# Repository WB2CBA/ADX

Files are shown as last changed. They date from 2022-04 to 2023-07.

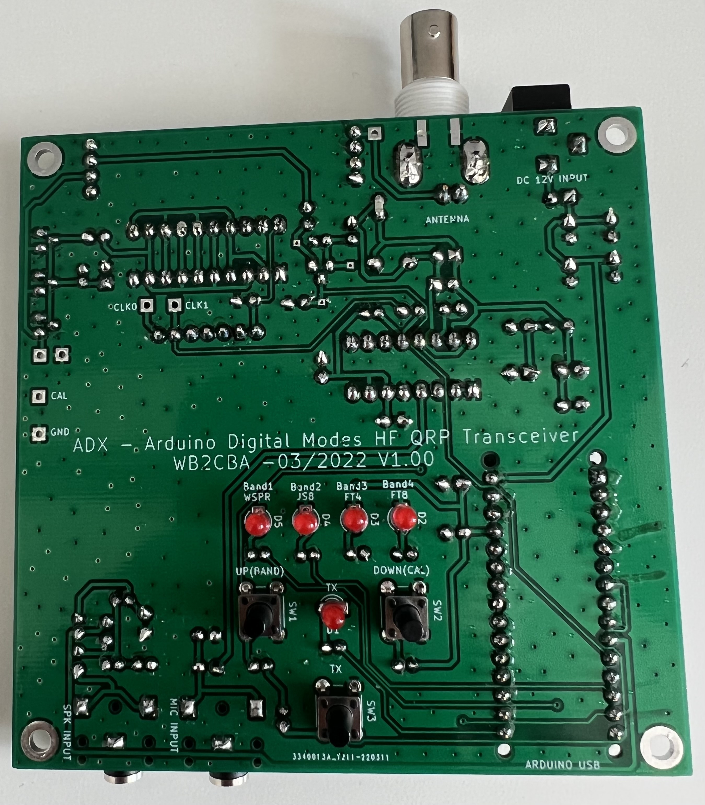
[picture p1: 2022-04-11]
ADX solder side photo.jpg

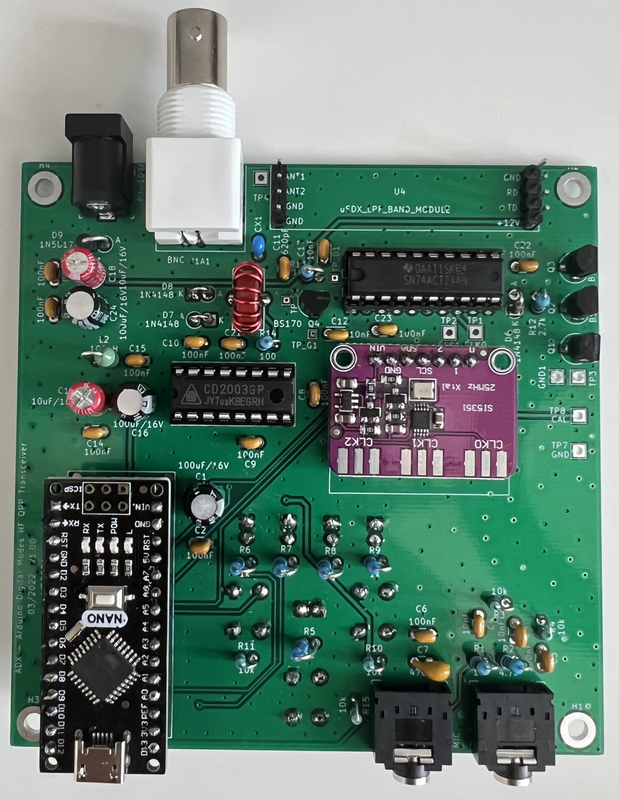
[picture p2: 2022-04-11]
ADX Component side photo.jpg

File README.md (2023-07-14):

ADX - Arduino Digital Modes Transceiver UPDATE (14 July 2023):

- Cowtown Amateur Radio Club ADX Buildathon Construction Manual added.

- I can't thank enough to Richard Hinsley, W5ARH/VK2ARH for putting together this detailed and extremely well put together build manual. 

- ADX Build Manual V1.5 Released.(10 June 2023)

- Calibration Procedure Changed to protect EEPROM from R/W wear out during calibration. (20 December 2022) 

- Caution Note on SI5351 Library.

- ZENER DIODE PA MOSFET PROTECTION to protect PA Mosfets from excessive SWR conditions.(20 December 2022)

- ADX_CAT_V1.6 - Band display bug corrections. Release Date: 14 July 2023  I would like to thank Peter Petrov, LA7WRA and Mark Culross, KD5RXT for spotting this rather embarrasing bug on my part.

-   Firmware release with CAT Control serial baud rate changed to 9600 bps to address problems on TS2000  CAT control on WSJT/X (Hamlib) with 115200 bps. Also excellent code structuring and cleanup  thanks to Joerg Frede,DK3JF. 

- I also added .hex files into ADX Firmware folder. These .hex files can be uploaded to atmega328p microcontroller via ISP port using a programmer like usbasp. 

- These .hex can be used to upload ADX firmware without using Arduino ide and compiling.

- SI5351 Module pull up resistor fix update added to Build Manual V1.4 (08 April 2023)

IMPORTANT NOTE ON NT7S SI5351 LIBRARY VERSIONS   

Please install SI5351 Library that is in ADX Github under ADX Firmware! 
Or use Etherkit SI5351 Library Version 2.1.3. 
ADX firmware is compatible with only Etherkit SI5351 Library version 2.1.3.
____________________________________________________________________________

ADX is an Arduino based Digital Modes Transceiver.

- ADX - is abbreviation for Arduino Digital Xceiver.

- ADX is a mono band (actually quad band) digital modes optimized HF transceiver that can cover four pre-programmed bands one band at a time by swapping Band LPF Modules. 
It can work on 80m, 40m, 30m,20m, 17m, 15m and 10m bands and can operate on four of the most popular digital modes, FT8, FT4, JS8call and WSPR.

- ADX now supports CAT via emulating KENWOOD TS2000 HF Transceiver with 9600 bps,8,1 Serial comm. CAT controls Band and Mode changes.

My goal with this project is to design a simple HF Transceiver optimized for operating on Digital modes:
-	Simple to procure – meaning not effected by chip shortage
-	Simple to build – 2 modules, 2 IC’s and 4 Mosfets!
-	Simple to setup and tune – One simple calibration procedure is all needed.
-	Simple to operate – Plug in ADX MIC to soundcard MIC input and ADX SPK to PC soundcard speaker input and we are good to go with any digital modes Software.
-	Dirt Cheap – Costs less than 25$ to get all parts and PCB if we exclude ridiculous shipping costs!

- Plug in a USB cable between ADX Arduino and your PC, Select Kenwood TS2000 with 9600bps,8,1 setup as your CAT rig and you will have CAT control on ADX!

- For ease of following which parts to solder while building Main board of ADX, Interactive BOM File - ibom_ADX.html file is a great help. Just run that file on Microsoft edge and follow each highlighted component and solder one by one. This interactive BOM was prepared by Gilles DELPECH - F1BFU. Thank you Gilles!

If you like my designs and would like to support my work:
https://www.buymeacoffee.com/wb2cba

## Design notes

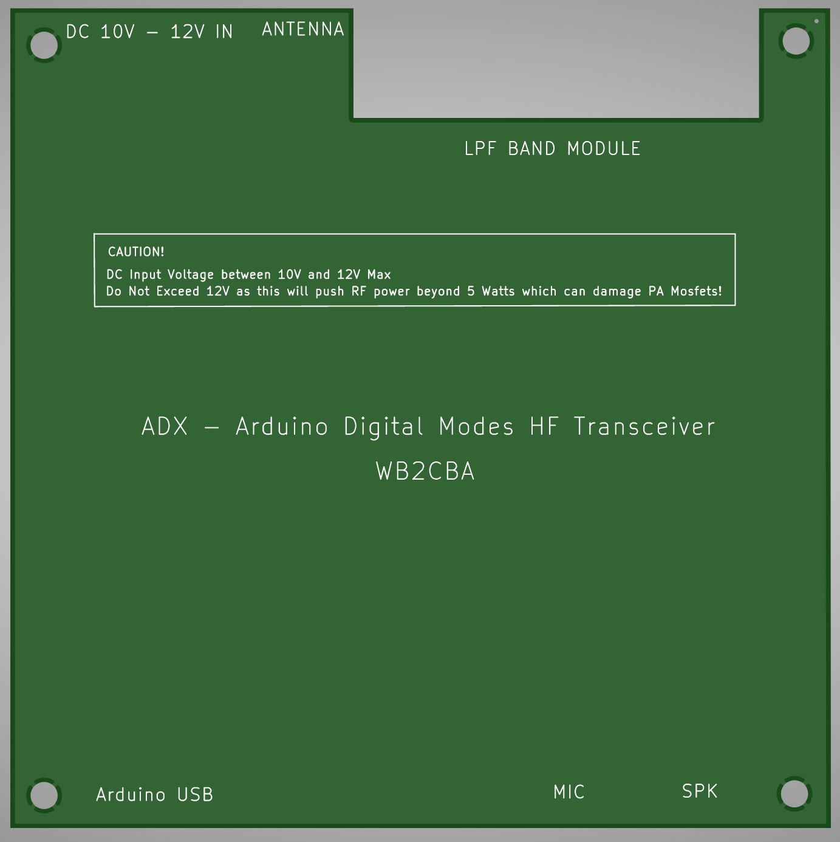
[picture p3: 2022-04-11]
ADX Schematics and Layout/ADX BACK PANEL LAYOUT.jpg

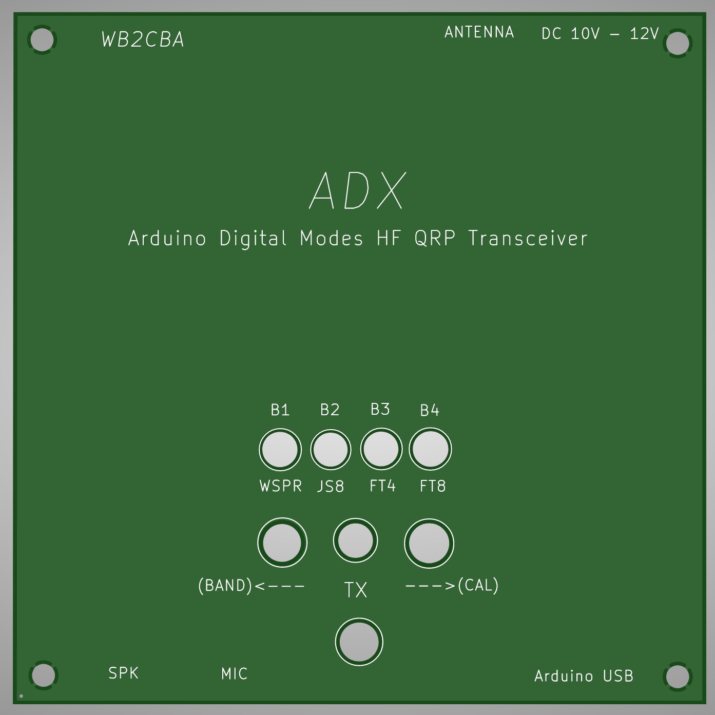
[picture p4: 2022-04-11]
ADX Schematics and Layout/ADX FRONT PANEL LAYOUT.jpg

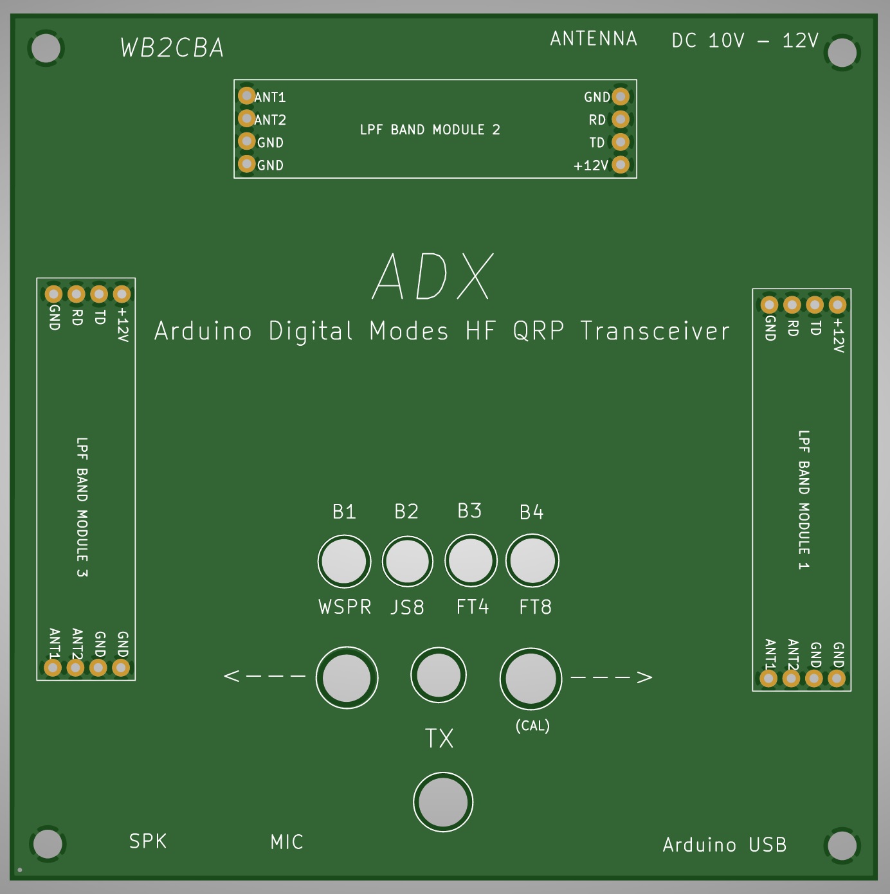
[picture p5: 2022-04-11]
ADX Schematics and Layout/ADX FRONT PANEL with LPF Carrier layout.jpg

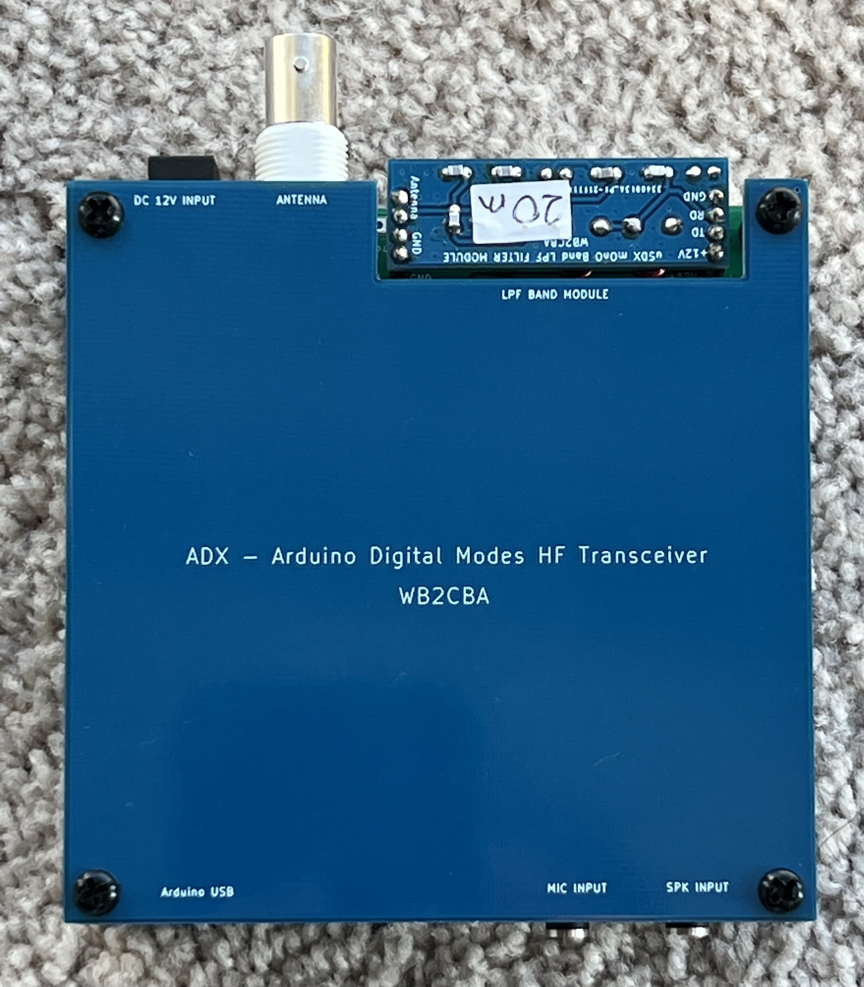
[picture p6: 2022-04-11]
ADX Bottom view.jpg

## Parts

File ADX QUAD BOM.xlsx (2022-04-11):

Part | Designator | Footprint
100uF/16V | C1,C16,C24 | Capacitor_THT:CP_Radial_D5.0mm_P2.50mm
620pF | C11 | Capacitor_THT:C_Disc_D3.0mm_W1.6mm_P2.50mm
10nF | C12,C17 | Capacitor_THT:C_Disc_D3.0mm_W2.0mm_P2.50mm
10uF/16V | C13,C18 | Capacitor_THT:CP_Radial_D5.0mm_P2.50mm
100nF | C2,C3,C6,C8,C9,C10,C14,C15,C19,C20,C21,C22,C23 | Capacitor_THT:C_Disc_D3.0mm_W1.6mm_P2.50mm
10nF | C4,C5 | Capacitor_THT:C_Disc_D3.0mm_W1.6mm_P2.50mm
470nF | C7 | Capacitor_THT:C_Disc_D3.0mm_W1.6mm_P2.50mm
SPK | CON1 | digikey-footprints:Headphone_Jack_3.5mm_SJ1-3523N
MIC | CON2 | digikey-footprints:Headphone_Jack_3.5mm_SJ1-3523N
TX | D1 | LED_THT:LED_D3.0mm
FT8 | D2 | LED_THT:LED_D3.0mm
FT4 | D3 | LED_THT:LED_D3.0mm
JS8 | D4 | LED_THT:LED_D3.0mm
WSPR | D5 | LED_THT:LED_D3.0mm
1N4148 | D6 | Diode_THT:D_A-405_P2.54mm_Vertical_AnodeUp
1N4148 | D7,D8 | Diode_THT:D_A-405_P2.54mm_Vertical_KathodeUp
1N5817 | D9 | Diode_THT:D_A-405_P2.54mm_Vertical_KathodeUp
SMA | J1 | SMA_EDGE:SMA_Samtec_SMA-J-P-X-ST-EM1_EdgeMount
BNC | J1A1 | Connector_Coaxial:BNC_Amphenol_B6252HB-NPP3G-50_Horizontal
PJ-102A | J2 | digikey-footprints:Barrel_Jack_5.5mmODx2.1mmID_PJ-102A
1uH | L1 | Inductor_THT:L_Toroid_Vertical_L10.0mm_W5.0mm_P5.08mm
100uH | L2 | Resistor_THT:R_Axial_DIN0204_L3.6mm_D1.6mm_P2.54mm_Vertical
BS170 | Q1,Q2,Q3 | Package_TO_SOT_THT:TO-92_HandSolder
BS170 | Q4 | Package_TO_SOT_THT:TO-92L_HandSolder
1M | R1 | Resistor_THT:R_Axial_DIN0204_L3.6mm_D1.6mm_P1.90mm_Vertical
2.7k | R12 | Resistor_THT:R_Axial_DIN0204_L3.6mm_D1.6mm_P1.90mm_Vertical
100 | R14 | Resistor_THT:R_Axial_DIN0204_L3.6mm_D1.6mm_P1.90mm_Vertical
4.7k | R2 | Resistor_THT:R_Axial_DIN0204_L3.6mm_D1.6mm_P1.90mm_Vertical
10k | R3,R4,R10,R11,R15 | Resistor_THT:R_Axial_DIN0204_L3.6mm_D1.6mm_P1.90mm_Vertical
1k | R5,R6,R7,R8,R9,R13 | Resistor_THT:R_Axial_DIN0204_L3.6mm_D1.6mm_P1.90mm_Vertical
UP(BAND) | SW1 | Button_Switch_THT:SW_PUSH_6mm
DOWN(CAL) | SW2 | Button_Switch_THT:SW_PUSH_6mm
TX | SW3 | Button_Switch_THT:SW_PUSH_6mm
CD2003GB_GP | U1 | Package_DIP:DIP-16_W7.62mm_Socket_LongPads
SI5351_Module | U2 | VFO_footprint:SI5351 Module_Vertical
74ACT244 | U3 | Package_DIP:DIP-20_W7.62mm_LongPads
uSDX_LPF_BAND_MODULE | U4 | uSDX_LPF_BAND_MODULE:uSDX_mOnO LPF_Band_Module
Arduino_Nano_Socket | XA1 | Arduino:Arduino_Nano

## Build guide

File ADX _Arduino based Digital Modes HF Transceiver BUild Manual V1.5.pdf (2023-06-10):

## ADX – An Arduino based HF Digital Modes Transceiver

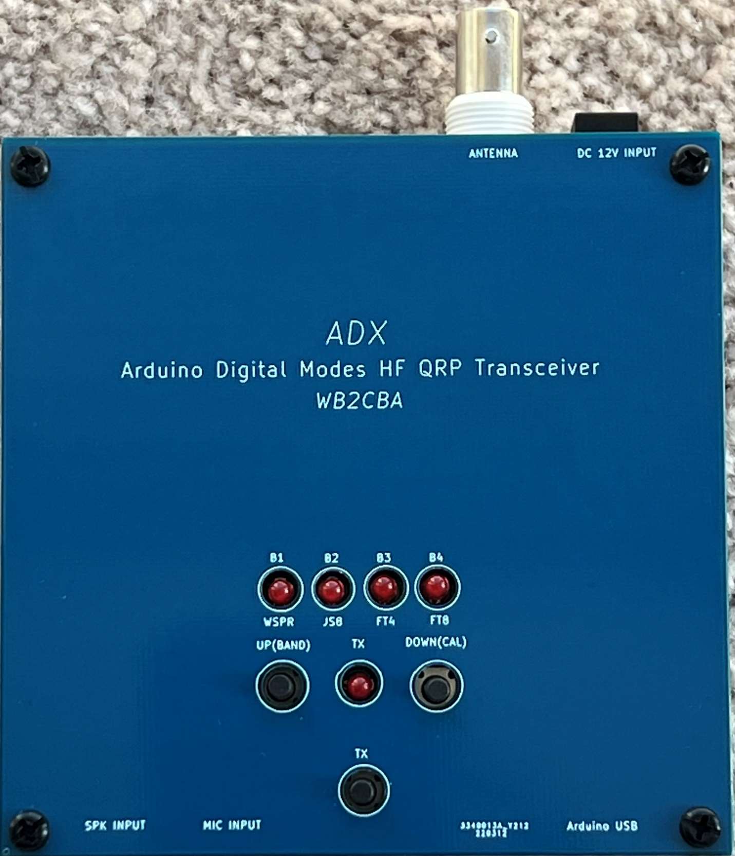
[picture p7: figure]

## Build Manual V1.5

## UPDATE:

- Calibration Procedure Change.
- Caution Note on SI5351 Library.
- ZENER DIODE PA MOSFET PROTECTION.
- CAT Control Functionality added. Changing CAT baud rate to 9600 bps as hamlib has problems with 115200 bps for TS2000.
- FSK TX code improved to perform under 500 Hz audio TX.
- ADX_CAT_VX.X Firmware
- SI5351 Module Pull UP Resistor FIX
ADX is an Arduino based Digital Modes Transceiver. ADX is abbreviation for Arduino Digital Xceiver. So where does thing come from?

When QRP labs released QDX Transceiver for Digital Modes I watched with fascination Hans Summers’s youtube video explaining details of QDX. For me QDX is the perfect optimized Transceiver for digital modes. Inspired by QDX I decided to put together my own!
Of course I wasn’t Hans Summers and QRP Labs so no way I had all that programming and RF skills to create something as sophisticated as QDX so I cheated and settled for something super stripped and simple! I christened it as ADX. It has an Arduino which justifies “A” and it is for digital modes so a “D” and it is a transceiver so it is a “X”! ADX fit that purpose for naming

convention quite nicely!
ADX is a mono band (actually quad band) digital modes optimized HF transceiver that can cover four pre-programmed bands one band at a time! More on that later. It can work on 80m,40m,30m,20m, 17m, 15m and 10m bands and also covers four of the most popular digital modes, FT8, FT4, JS8call and WSPR. I thought about using SA612 though this CD2003GP IC gave much better sensitivity results as it has a RF preamplifier section and it is dirt cheap and readily available from every online Chinese marketing site!
My goal with this project is to design a simple HF QRP Transceiver optimized for Digital modes:
- Simple to procure – meaning not effected by chip shortage
- Simple to build – 2 modules, 2 IC’s and 4 Mosfets!
- Simple to setup and tune – One simple calibration procedure is all needed.

- Simple to operate – Plug in ADX MIC to soundcard MIC input and ADX SPK to PC soundcard speaker input and we are good to go with any digital modes Software.
- Dirt Cheap – Costs less than 25$ to get all parts and PCB if we exclude ridiculous shipping costs! ADX Building Blocks:

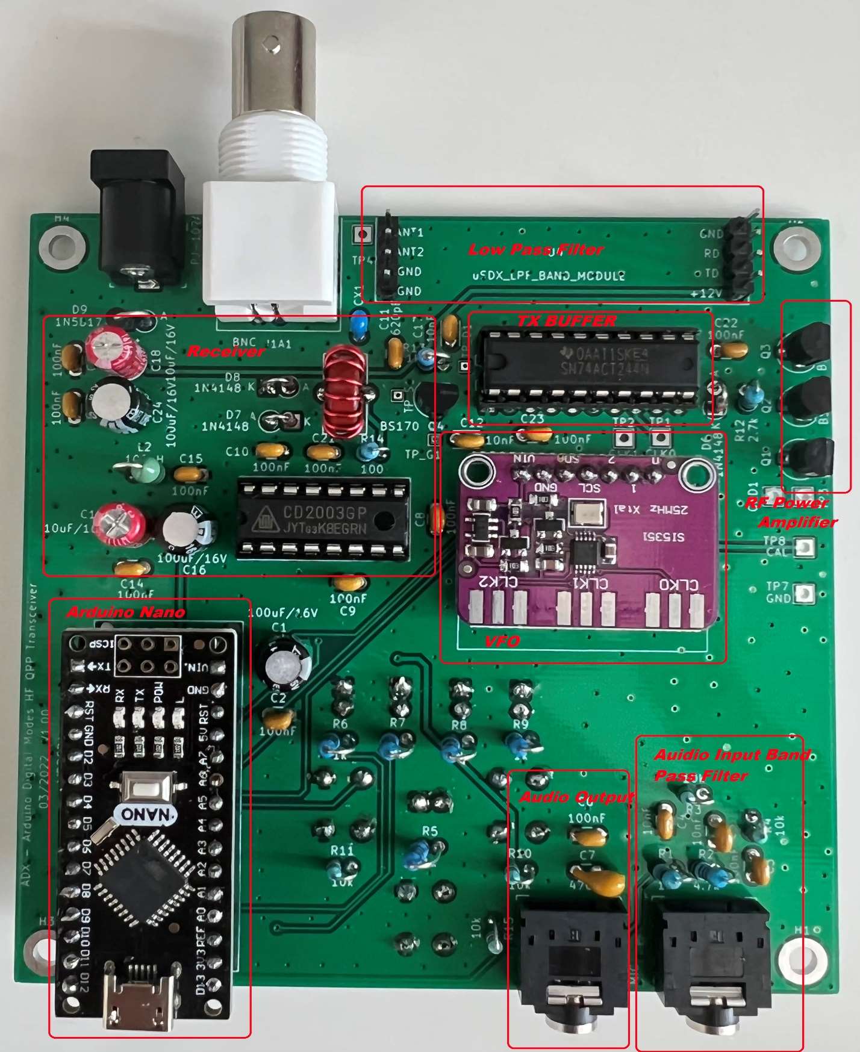
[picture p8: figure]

Building blocks of ADX Transceiver:
- Brain of ADX is an Arduino Nano which takes care of signal generation from audio tones of digital modes, user interface and calibration of SI5351 Module. ADX uses direct FSK Signal generating method similar to QDX or QRPGUYS Digital Transceiver III.
- Audio interface consists of a Speaker input from PC sound card which is actually an input to Arduino nano analog comparator for tone frequency detection and sampling. Before inputting signal to analog comparator of Arduino it passes through a band pass filter which has an audio band pass frequency range of 500 Hz to 3500 Hz.

This input acts like a VOX so no need for any PTT or serial PTT CAT input. When ADX hears a tone from for example WSJT/X audio output it starts transmitting. And when the tone of digital mode stops it stops TX. It’s that simple. The AFP-FSK (Audio frequency processed Frequency shift keying) technique used in ADX is developed by Burkhard Kainka(DK7JD) - http://elektronik-labor.de/HF/SDRtxFSK2.html

So how does this actually work?
Any digital tonal mode consists of varying audio tones that change frequency in relation to the data they correlate to. This audio tone generated for example for FT8 with WSJT/X software is passed through an audio band pass filter and then it is compared with Arduino Nano’s Atmega328P processor A/D comparator for start and stop zero cross detection to determine period of that tone. From that period, frequency of that particular tone that is determined and added to base transmit frequency, for example 14074000 Hz for 20m FT8. If the tone let’s say is 1000 Hz then the carrier TX is now 14074000 Hz + 1000 Hz = 14075000 Hz.
As it is summed it will be in USB frequency range of any SSB receiver though the signal is not pure SSB signal still any SSB TRX set to USB can’t tell the difference! This tone frequency detection and adding to base frequency is continuously repeated 400 times per second and refreshed until the FT8 tone transmission generation is over. In that case TX stops.
What fascinates me about this FSK signal generation technique is to generate a signal that is received in USB without any SSB mixing or filtering which eliminates problems of IMD or phase differences etc that comes with SSB signal generation technique which allows such a simple Transceiver to be conceived with minimal parts.
- VFO: VFO is a classic cheap SI5351 Module from Aliexpress or any other site similar to that. VFO generates CLK0 TX signal, CLK1 RX signal and CLK2 calibration signal. No need to modify SI5351 Module as we did in uSDX rig builds. SI5351 module works in a cozy 400khz I2C speed.
- TX BUFFER: TX buffer is an inverting 74ACT244 octal buffer connected in parallel to drive Class E RF power amplifier consisting of 3 x BS170 mosfets. RF power output -varies from band to band - around 5 watts.
- Low Pass Filter Module is a serial resonance class E LPF filter similar to that one used in uSDX designs.
- RECEIVER is CD2003GP – A Chinese clone of Toshiba’s TA2003GP AM/FM radio IC. Only AM section is used as a direct conversion receiver.
- And some caps for RF and VCC filtering etc.
- 5 LEDs and three tactile pushbutton switches for user visual interface and controls. No fancy displays or rotary encoders!
- Now we have CAT support!

Here is ADX Schematics:

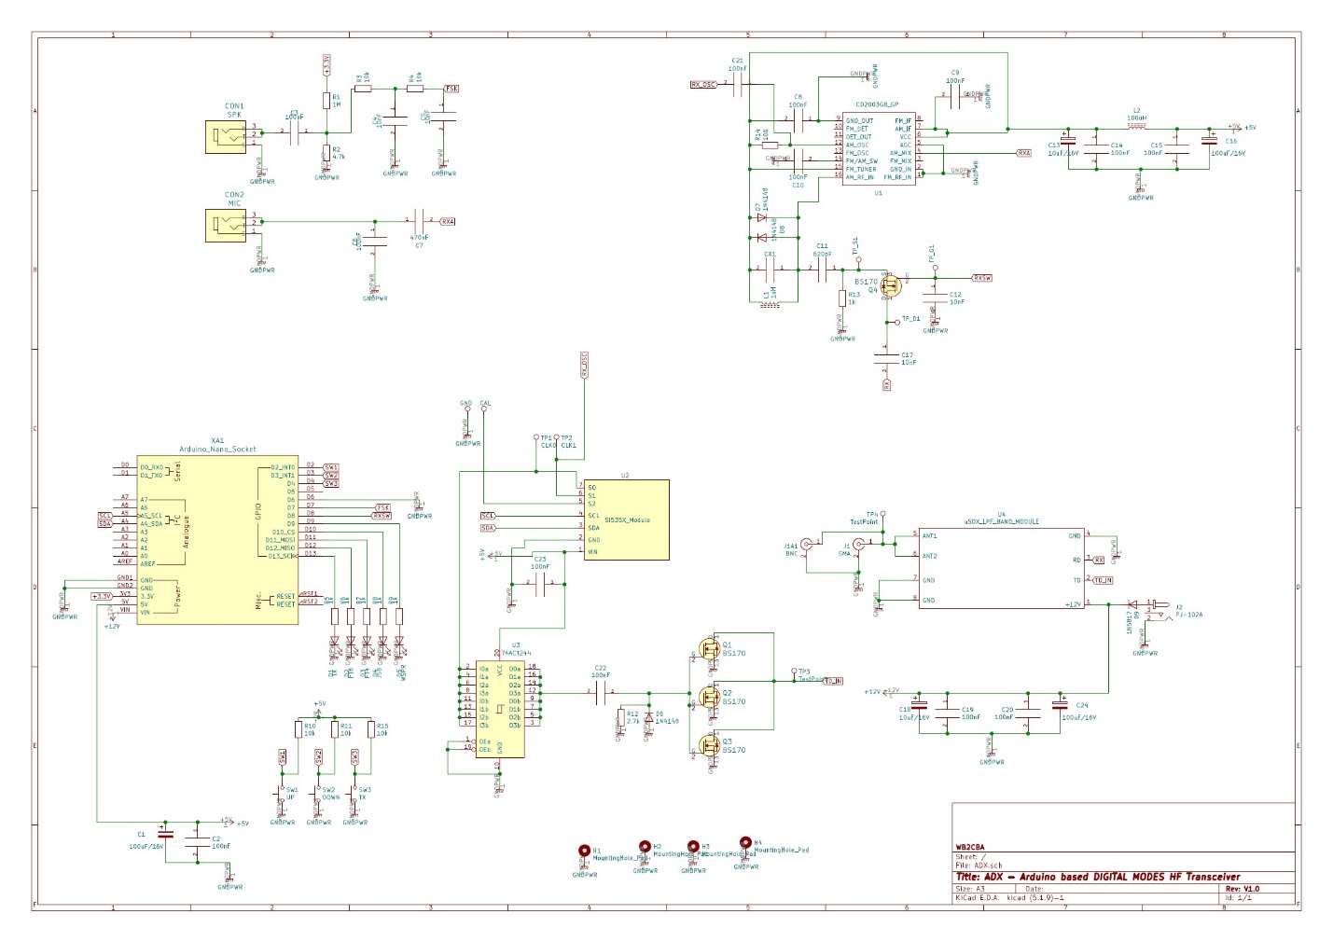
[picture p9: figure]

Here is ADX PCB layouts:

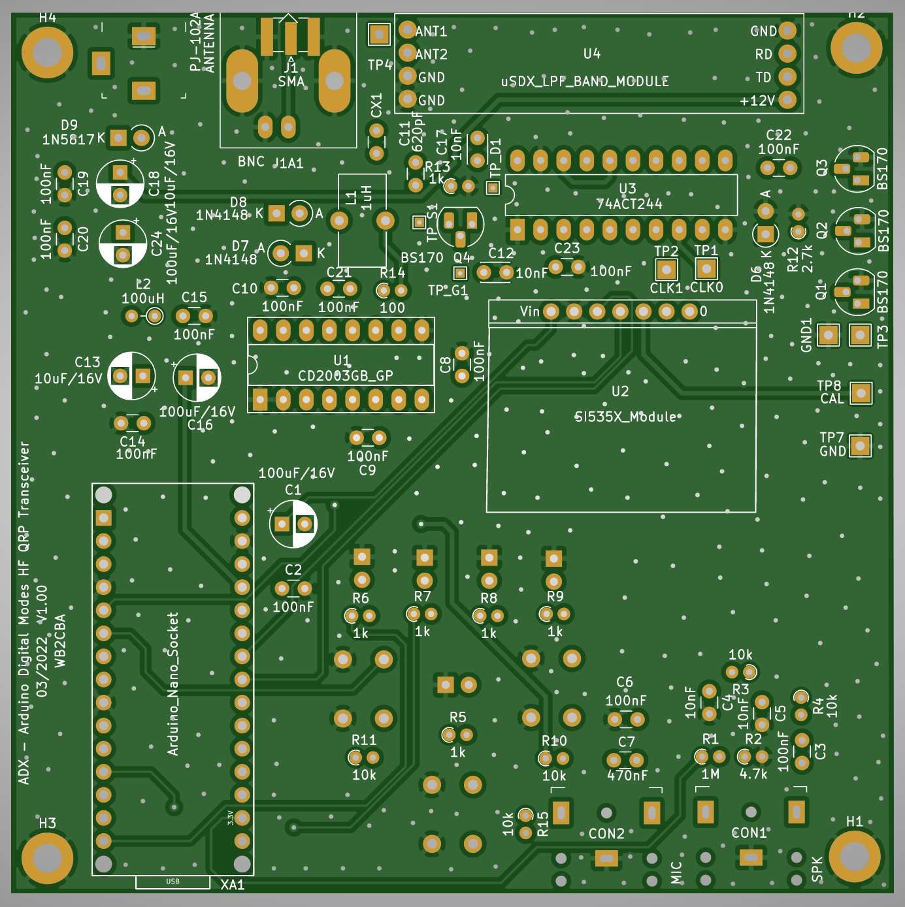
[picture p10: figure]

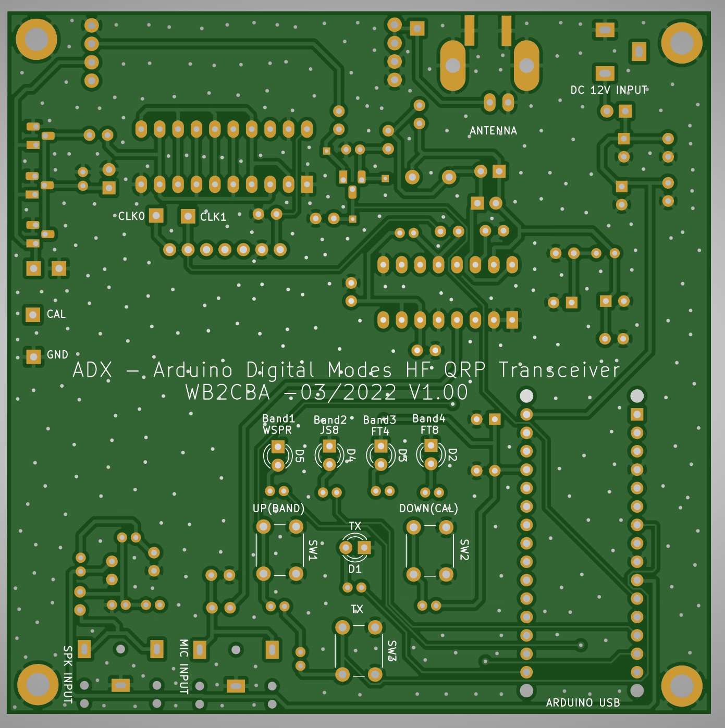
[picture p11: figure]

These are Top and Bottom Panels to give a professional rig appearance to ADX !

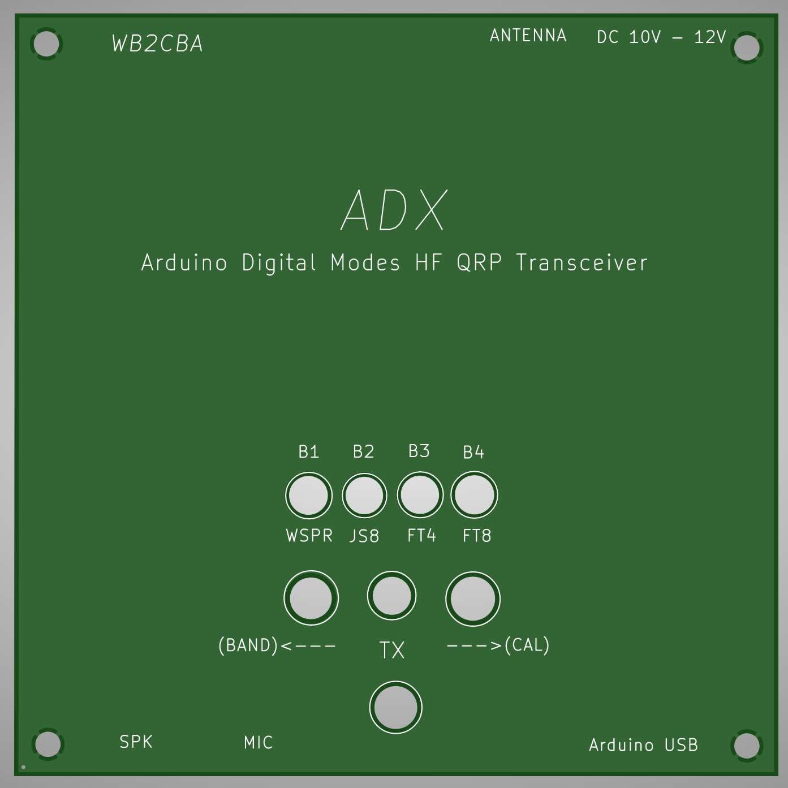
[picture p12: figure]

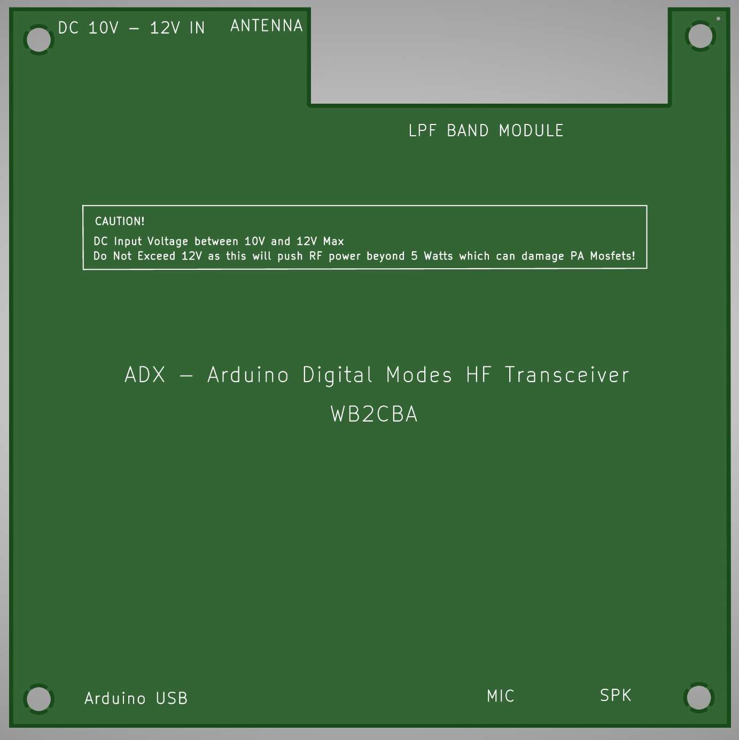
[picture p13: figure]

ADX Top Panel with LPF carrier slots:
I even designed a top panel with LPF carrier slots so that extra 3 band LPFs can be carried on top of ADX transceiver! How crazy is that!

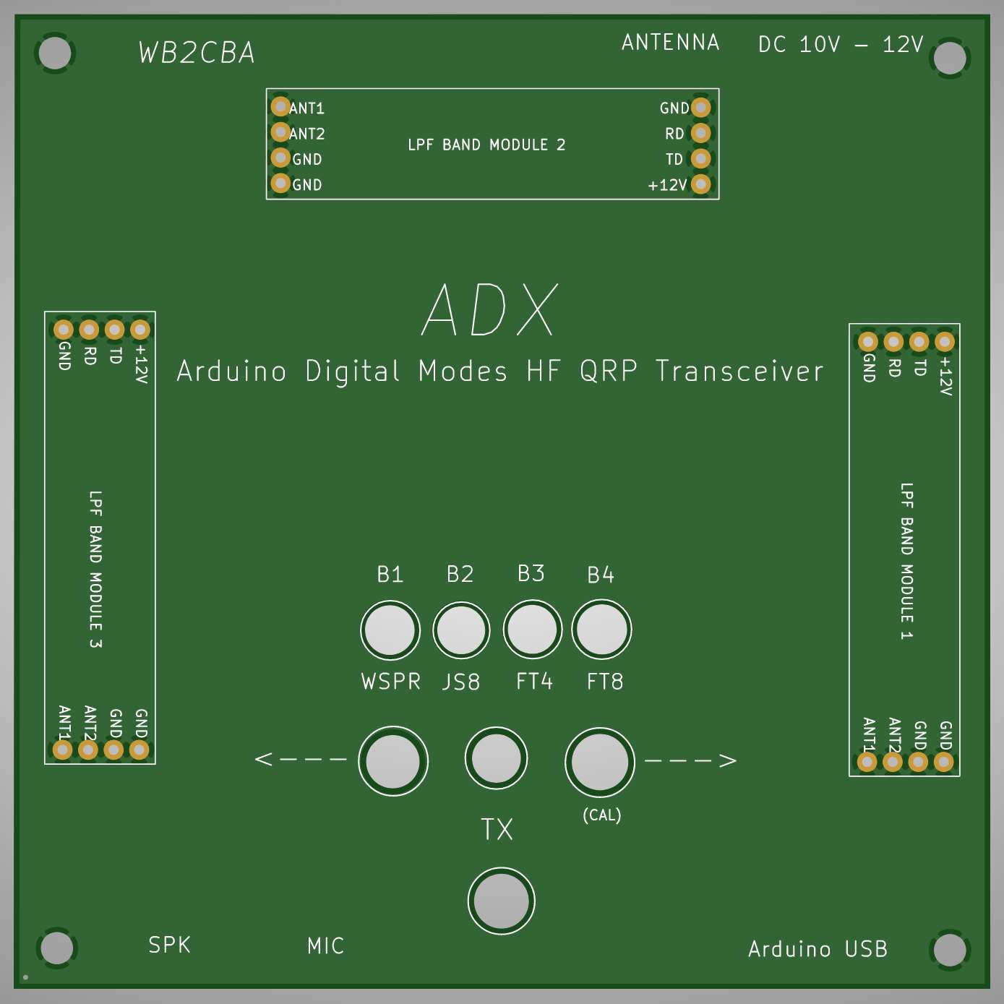
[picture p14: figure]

## 1- Building ADX:

Building ADX is simple and straight forward. All the files including Gerbers for PCBs and ADX firmware can be found in my GITHUB page on this link:
https://github.com/WB2CBA/ADX
Here is list of essential files in ADX Github page:
- ADX PCB gerber File
- ADX TOP panel Gerber File
- ADX BOTTOM panel Gerber File
- uSDX mOnO LPF Band Module Gerber File
- ADX Arduino Firmware
- SI5351 Library
- ADX User Build Guide - which is this write up
- ADX band dependent LPF Component Selection Excel sheet
- ADX BOM(Bill Of Materials) Excel Sheet
- The first step is to download all these files from ADX Github page.
- Now we need to order PCBs( Printed Circuit Board) for ADX :
The easiest way is to order from a Chinese PCB house online. I generally use www.jlcpcb.com . JLCPCB’s production is good quality , relatively cheap compared to quality and fast though shipping might be pricey if DHL is chosen to be faster. A cheaper shipping method is via snail mail which is regular post service though it is much slower.
To order a PCB first create an account with JLCPCB and upload supplied GERBER files in github page. There are videos on youtube how to upload and order PCBs from any of these online PCB houses. I strongly recommend to watch those if you haven’t ordered a pcb before.
- BOM excel sheet has all parts used in ADX. Parts used in ADX are not critical and not effected by part shortage as of writing of this article!
- Now if all parts and PCBs are gathered it is time to solder main pcb. I generally start with resistors and then capacitors. Then MOSFETS and LEDs and tactile switches. Don’t make an error, LEDs and switches are soldered on solder side of PCB!

- When soldering LEDs first solder switches. Then adjust LEDs so that top of each LED is flush with the top of switch lever. This way LEDs can stick their head nicely out of the top panel holes. Tactile Switches should be 6 mm lever ones.
- Now we can solder IC sockets and Arduino headers. I strongly recommend to use headers for Arduino nano. This way if something is not right it will be easy to replace nano. Same goes for IC’s.
- You can solder SI5351 module straight on to the pcb.
- The last items to solder are BNC, Power socket, Audio jack connectors and LPF headers.
- CX-1 is an optional capacitor for single band build giving a better band pass capacity. I added for experimental purposes. Not needed for the time being. Leave it blank.
- LX-1 is 1uH inductor made up of T37-2 toroid with 16 turns of 0.40 mm (AWG 26) enameled copper wire. Also a fixed 1uH inductor can be used.

This will complete main ADX PCB Build.

Now it is time to build LPF Band Filter Modules!

To use full four band capability of ADX Transceiver you need to choose four bands among 7 bands ADX supports.

These bands are 80m/3.5Mhz, 40m/7Mhz, 30m/10Mhz, 20m/14Mhz, 17m/18Mhz, 15m/21 Mhz and 10m/28Mhz.

Now for the chosen four bands four LPF band Modules needs to be assembled! By switching these 4 band LPF modules 4 different bands to operate can be covered.

2- ADX Band specific LPF(Low Pass Filter) BAND Modules:
ADX Transceiver uses Serial Resonance Low pass filter modules for each band it operates. For each band we choose to operate on we need to build a Band LPF Filter Module. We will swap these modules for the band we will operate on. Let’s say we want to operate FT8 on 40m/7Mhz band. Then we will grab and plug in 40m/7Mhz Band Module and select that band on ADX and Voila! Now we can operate ADX on 40m/7Mhz. Same applies to other bands. Although ADX is a mono band transceiver these plug in band modules gives it a multiband capability and flexibility.
ADX uses same LPF band module PCB of my uSDX mOnO transceiver. This way I didn’t have to design a new module. Lazy!
LPF band module PCB’s can be ordered by using GERBER file for uSDX mOnOLPF band Module. These Band filter modules can be built either using surface mount device (SMD)capacitors or through hole device(THD) capacitors.
Capacitor footprint on band module pcb allows to use 0805 or 1206 footprint standard SMD(Surface Mount Device) capacitors or 2.54 mm lead spacing THD(through hole) capacitors.
Toroids used are:
1x FT37-43
2 x T37-2 Red toroid or T37-6 Yellow toroid depending on band selection for each band module. Up to 20m/14Mhz band T37-2 toroids work pretty good. From 17m/18Mhz band to 15m/28Mhz band T37-6 yellow toroids are used.
Here is a photo of Band filter module built using THD(Through hole Device) capacitors:

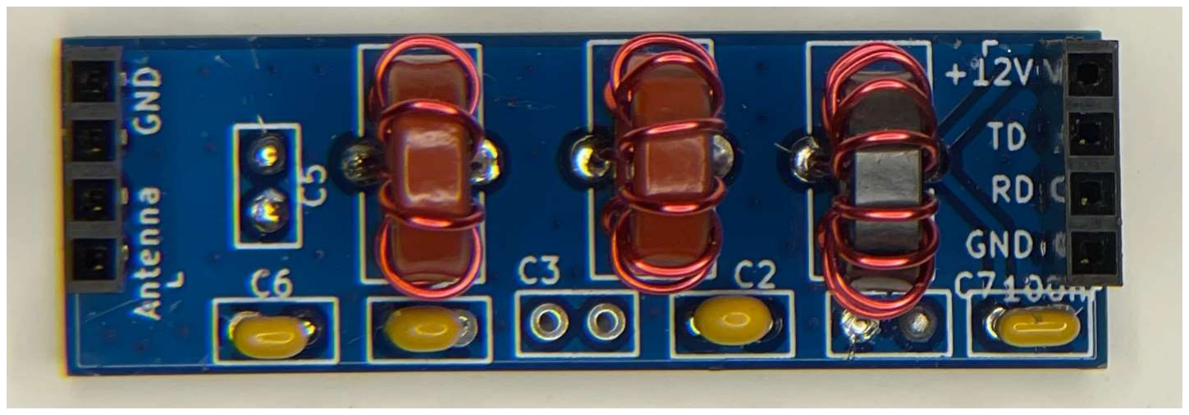
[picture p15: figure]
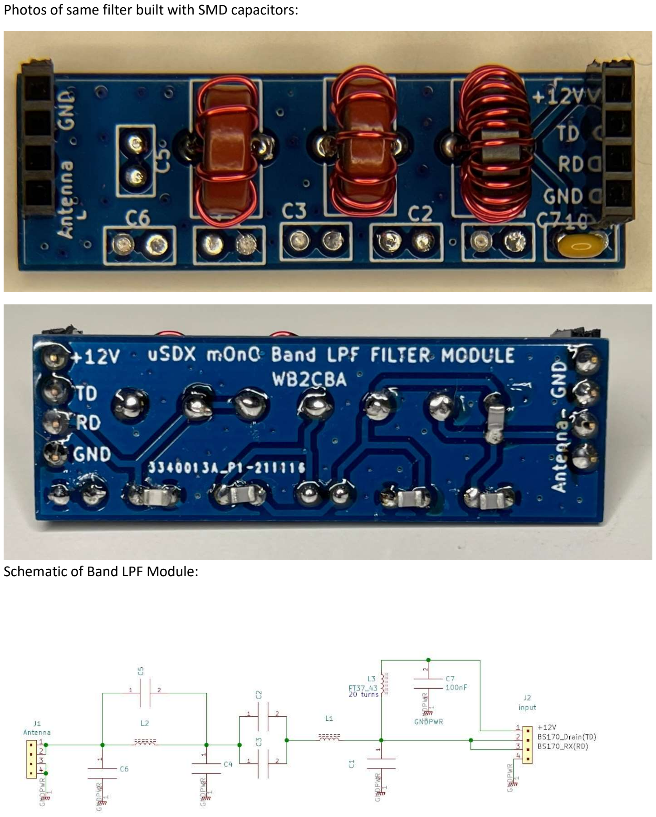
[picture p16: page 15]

Photos of same filter built with SMD capacitors:

Schematic of Band LPF Module:

BOM for LPF Band Module:
2 x 4 pin header – These headers can be male or female headers depending on what is soldered on RF board. These band module headers should the opposite mate of RF board 4 pin headers. i.e if we used male 4 pin headers on RF board then Band modules must have female 4 pin headers to plug in and vice versa.

### 1 x C1 – Band Dependent THD or 0805 NPO 100V or more Capacitor

### 1 x C2 – Band Dependent THD or 0805 NPO 100V or more Capacitor

### 1 x C3 – Band Dependent THD or 0805 NPO 100V or more Capacitor

### 1 x C4 – Band Dependent THD or 0805 NPO 100V or more Capacitor

### 1 x C5 – Band Dependent THD or 0805 NPO 100V or more Capacitor

### 1 x C6 – Band Dependent THD or 0805 NPO 100V or more Capacitor

### 1 x C7 – 100 nF THD or 0805 Capacitor (Non band dependent capacitor)

### 1 x L1 – T37-2 RED or T37-6 YELLOW toroid - Band dependent

### 1 x L2 – T37-2 RED or T37-6 YELLOW toroid - Band dependent

1 x L3 – FT37-43 Ferrite Toroid – 20 turns. Non band dependent and same detail applies to all band LPF Modules.
AWG 26 or 0.40 mm enameled copper wire can be used for Toroid turns.
So how are we going to know which capacitor values for each band required and what Toroid to be used for L1, L2 and L3 and turn for each band?
This table will help us choosing all band dependent component values and details for each band. Beware that these values are a bit differing from uSDX mOnO band module values, they are optimized for ADX Transceiver.

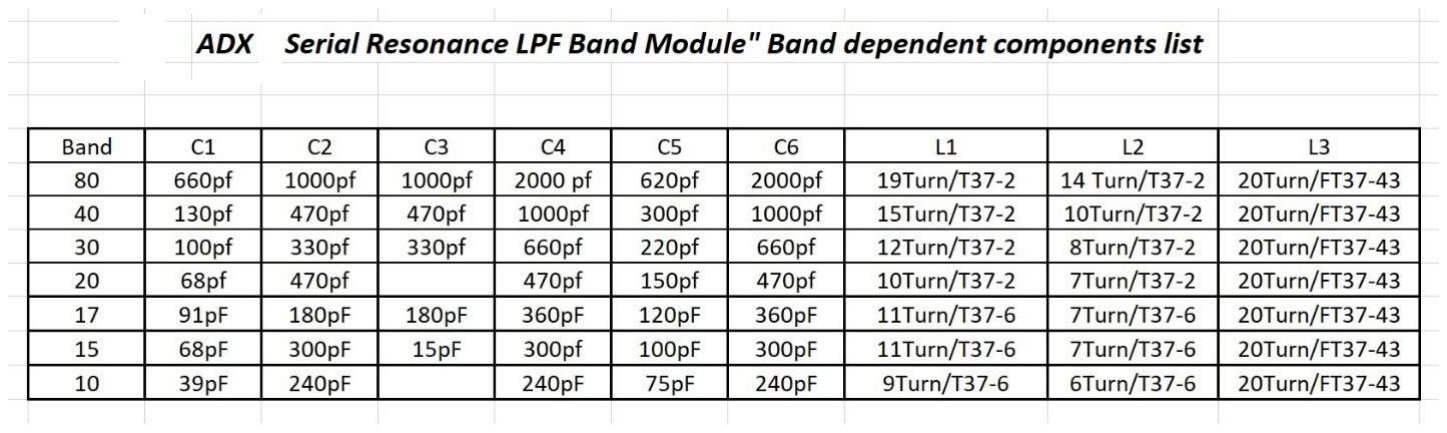
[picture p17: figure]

This table is a base for building various band LPF modules. If you have a knack to experiment and need a bit more power here are some useful tips:

1- Lower one turn from L1 in each band. This will slightly increase RF output power though might increase TX current too so exercise caution!
2- For L3 12 turns also works pretty good so this can be a nice option to play with.
Though caution here! DO NOT EXCEED 5 WATTS RF POWER! Otherwise BS170 voltage limit will be exceeded which will end up in magic smoke!

CLASS E RF POWER AMPLIFIER BASICS and Some useful tinkering knowledge:
ADX Transceiver uses Class E type RF power amplifier scheme. Class E is an efficient class of power amplifier which can go up to 85 to 90 % efficiency which means less thermal heat dissipation on RF power transistors and lower supply current vs more RF power output. These are the advantages of Class E RF amplifiers. Disadvantage of this amplifier type is it is harder to tune and get the required efficiency when compared to other classes like Class A,B or C amplifiers. ADX uses this efficient class E amplifier like uSDX transceiver. 3 x BS170 mosfet transistors parallel when tuned properly can easily give up to 5 watts RF output power without dissipating any excess heat under 12V DC.
uSDX mOnO LPF band filter board consists of all parts related to fine tune ADX Class E mosfet Power amplifier. Above table has component values of each LPF Band Filter which will give a reasonable power efficiency on all 6 bands covered. Efficiency values for each band can be further tweaked and it is a great way to learn and experiment with class E amplifiers. ADX uses so called serial resonance LPF design for Class E and all values are calculated by WA0ITP’s excellent excel Class E design spreadsheet: http://www.wa0itp.com/class%20e%20design.html
Here are some class E readouts for curious ADX kit Builders: http://www.norcalqrp.org/files/Class_E_Amplifiers.pdfhttps://people.physics.anu.edu.au/~dxt103/class-e

TIPS on TOROID Winding:

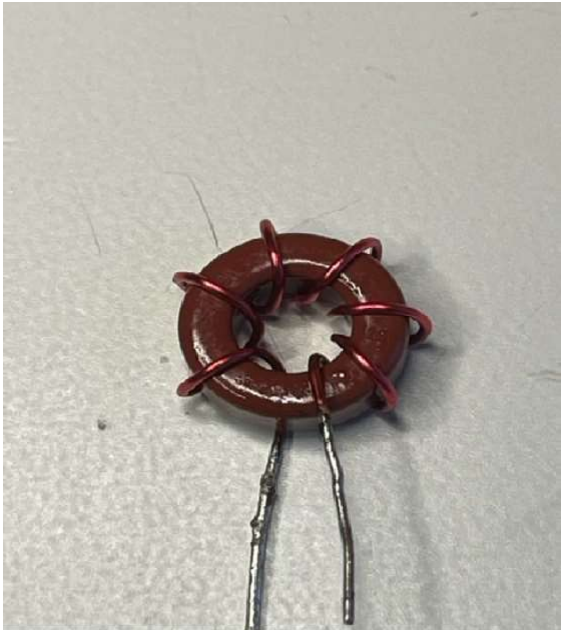
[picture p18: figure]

This is T37-2 RED Toroid with 7 turns of enameled copper wire.

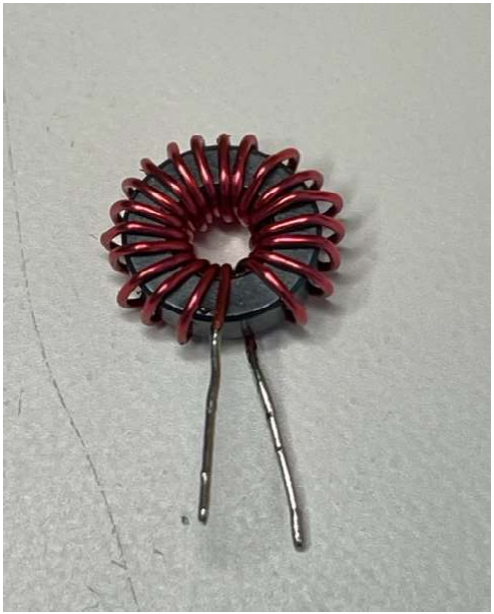
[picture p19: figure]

This is FT37-43 L3 Toroid with 20 turns of enameled copper wire.

One important point to consider is that the edges of FT37-43 Toroids are quite sharp which can scrape enamel coating on inductor wire. To fix this issue the easiest method is tapering the edge a little with an oversized drill bit. Use the oversized drill bit to turn with your fingers inside the toroid ring to smoothen out sharp edges. Do not use a drill to turn the drill bit! You will snap the toroid and most importantly will harm your fingers in the process!

3- One turn means enameled copper wire passes once inside the toroid ring. For example, in 7 turns T37-2 toroid in the above photo wire passes 7 times inside the ring.
4- Always after passing the turn stretch the wire so it is tightly wound around the toroid.
5- When all turns are in count carefully every turn that passes through the inner ring of toroid. The best method to do is to take a close up photo of the toroid and count the turns. This way it is easier to see turns and you won’t miss a turn.
6- Never ever let one turn go over another one. Every turn should be side by side! This is important in toroids that have 20 or more turns and it is easy to overlap turns.
7- Always scrape ends of toroids to clean enamel coating for soldering. To clean enamel coating there are two methods which can be used separately or together.
Scraping enamel coating with a cutter knife thoroughly and then apply a bit solder coating. Second method is to heat up wire with soldering iron so that enamel coating just burns out and then cover with a solder coating. Scraping first and then burning the residue enamel coating is the best approach! Then apply a bit solder coating before soldering toroid into pcb.
8- Before soldering wound toroid try to spread as even as possible as in the photos above.
9- After soldering toroid in its place check with a continuity tester if solder joints are okay and connected electrically.

ADX CLASS E RF POWER AMPLIFIER MOSFET HIGH SWR PROTECTION and SI5351 Pull Up resistors Fix: While experimenting with ADX transceiver I smoked out BS170 mosfet many times due to high SWR or operating without antenna!
So I tinkered to find a way to prevent MOSFET demise in case of bad or excessive SWR! And thankfully there is a very simple solution to prevent just that! A 47Volt 1 Watt zener diode is all needed and works like charm! The beauty of this zener protection is even without antenna no harm will be done to PA Mosfets!

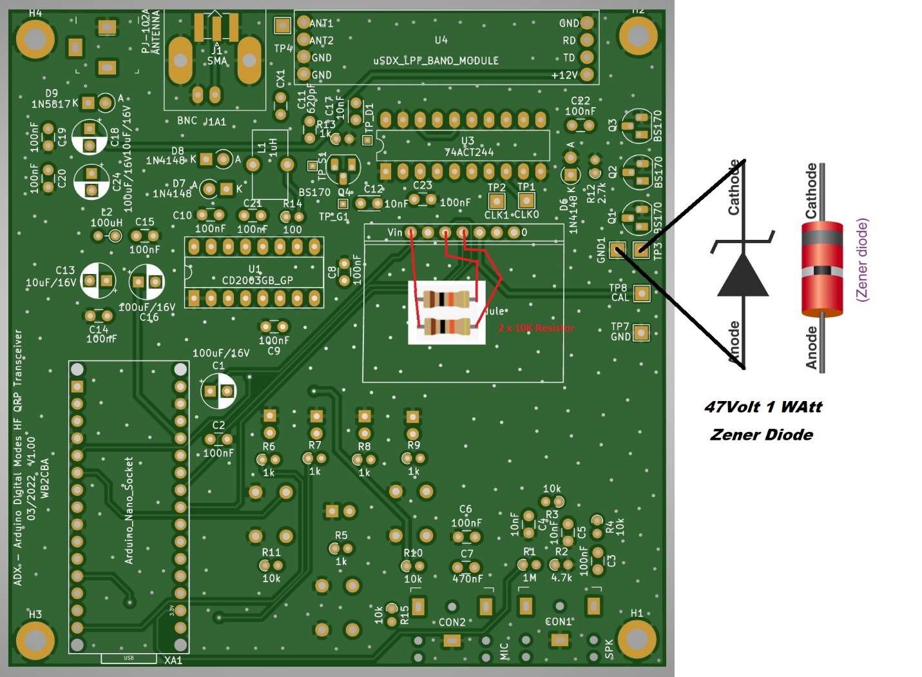
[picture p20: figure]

Solder 47V / 1 Watt zener diode as shown in the photo above between TP3 and GND solder points in ADX PCB. Cathode of Zener Diode goes to TP3 test point and Anode of zener diode goes to GND1 test point. Zener diode can be any zener diode with 47V and 1 Watt rating. I used 1N4756 from On semiconductor. The other option can be BZX85C47 zener.
This will protect your PA mosfets from accidental smoke out! I strongly recommend to add this zener to your ADX pcb.
Here is my test video on youtube with another variant of ADX called ADX UnO which identical to ADX but with smd components:
https://youtu.be/7hUmkE84kfA

SI5351 Modules are coming in various qualities and they are not identical sadly. Some of these modules don’t have I2C pull up resistors on them. If there is no pull up resistor then Arduino can’t address I2C ports SDA and SCL as they are open collector and needs to be pulled up by 10k resistors. If you are experiencing SI5351 related no signal generation fault it will be a good idea to add those two 10k resistors as shown in the photo above to cure that problem.
ADX FIRMWARE:
ADX firmware is developed in Arduino C language and Arduino IDE can be used for visualization and experimenting with it.
ADX uses Arduino Nano board as microcontroller. This is a readily available and cheap Arduino development board that can be outsourced easily online.
The current version is updated to ADX CAT VX.X. X.X stands for version number. This will change as new features will be added. I will continue working on firmware in the future so this version number can increase with new features. So check out occasionally ADX Github site for an update! New features are listed at the first page of this manual in bold.
SI5351 needs an Arduino library to work with. This library is Jason Mildrum, NT7S’s SI5351 library with Version 2.1.3, Si5351Arduino-master.zip .
DO NOT USE Jason Mildrum NT7S’s latest version of SI5351 library from his github site as it is not compatible anymore with ADX firmware. Use SI5351 Library that is in ADX Github firmware page to avoid any I2C communication problems. ADX is using version 2.1.3 of NT7S SI5351 Library.
Install this library as you install any arduino library. Using Sketch/Include Library/Add .ZIP Library menu. Just select the above .zip file and it installs. Do not unzip the file!

ADX_CAT_VX.X.ino is the ADX firmware file and can be downloaded from ADX github page: https://github.com/WB2CBA/ADX
Before we upload ADX firmware we need to setup band assignment in the firmware for our needs! Which is assigning four preferred bands we plan to operate on. If default band assignment of Band 1 = 40m, Band 2 = 30m , band 3 = 20m and Band 4 = 17m is preferred band setup then skip this step.

This is the band assign code lines from ADX firmware which needs to tailored for our preference:

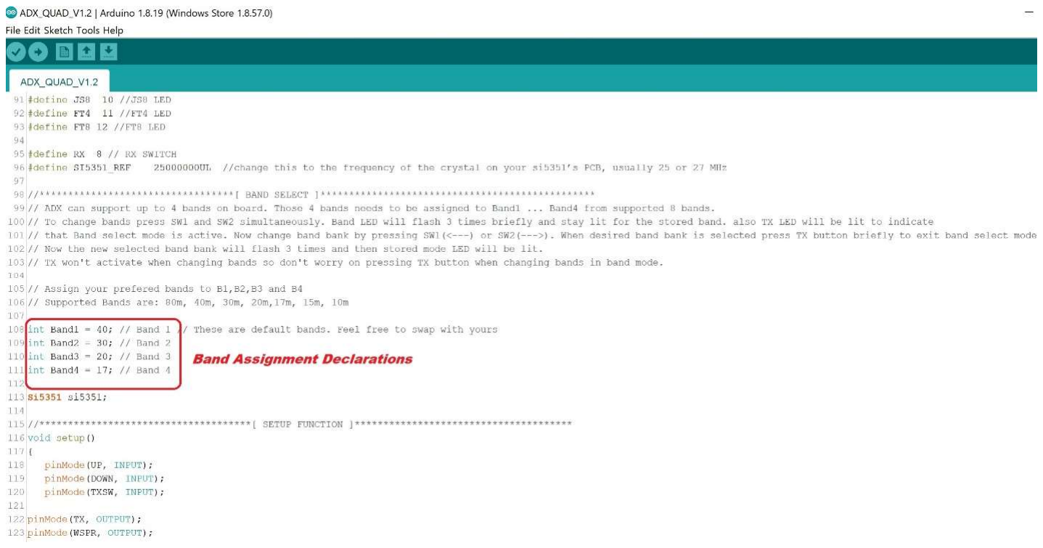
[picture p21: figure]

Assign your own preferred bands to those locations in the firmware which is inside the red rectangle above. My preferred bands are 40m for Band1, 30m for Band2, 20m for Band3 and 17m for Band4.
After this band assignment we can compile and upload ADX firmware to Arduino Nano as uploading to any Arduino board. Nothing special here.
First Power up and smoke test!
After firmware upload we are ready for first smoke test! Do not install LPF Band module at this time. Connect 12V DC power source.
DO NOT USE More than 12V DC for ADX Transceiver as this pushes RF power output beyond 5 Watts and over 60V which is over max limit of BS170 MOSFETS. This can release magic smoke on mosfets!
Now measure voltage of 12V and 5V in different locations such as IC VCC pins etc. to make sure everyone gets the right voltage share!

If all is ok in terms of voltage now we can test if SI5351 is generating any signal. To do this use a frequency counter or oscilloscope on CLK1 test point. The default band is Band 1 and default mode is FT8. You should observe your choice of band 1 base frequency for FT8. For example in my case my Band1 is 40m and for FT8 it is 7074000 Hz or anything close to that as we didn’t yet calibrated the SI5351 VFO. The important point is to see some kind of signal generation which is tell tale of SI5351 is working!
If no smoke and nasty smell and there is signal from SI5351 then we are in business and passed the smoke test!
(Calibration Procedure for SI5351 VFO: )
For SI5351 VFO Calibration Procedure follow these steps:
1 - Connect CAL test point and GND test point on ADX PCB to a Frequency Counter or Oscilloscope that can measure 1 Mhz up to 1Hz accurately.
2 - Press SW2 / --->(CAL) pushbutton and hold.
4- Power up with 12V or with 5V by using Arduino Nano USB socket while still pressing SW2 / --->(CAL) pushbutton.
5 – When FT8 LED and WSPR LED flashes 3 times and stay on, release SW2 / --->(CAL).
Now Calibration mode is active.
6 - Using SW1(<---) and SW2(--->) pushbuttons change the Calibration frequency until reading 1 Mhz = 1000000 Hz exact to the nearest hertz on Frequency counter or Oscilloscope.
The waveform is Square wave so frequency calculation can be performed easily.
7 - If you read as accurate as possible 1000000 Hz then calibration is done.
8 - Now we must save calibration value to EEPROM location.
9 – In order to save calibration value press TX button briefly. TX LED will flash 3 times which indicates that Calibration value is saved.
10 – Now Power off ADX.
DO NOT FORGET TO SAVE CALIBRATION VALUE BY PRESSING TX BUTTON BRIEFLY AT THE END OF EACH CALIBRATION SESSION. OTHERWISE CALIBRATION WILL REVERT TO THE DEFAULT VALUE.
Calibration will be loaded back in every power up so no need to repeat calibration once done. Also new firmware update won’t reset calibration and no need to re-calibrate again.
After calibration, plug in desired LPF band module. To activate Transmit for testing purposes we can always use TX button which acts as a ordinary PTT(Push To Talk) button and no need to connect to a digital modes software for transmit. This RF output a continuous wave signal only for testing RF power. Also this can be used for Antenna Tuner tuning.

Using ADX Arduino Digital Modes Transceiver:
ADX Arduino Digital Modes Transceiver can be used with CAT control via USB or using Manual control via switches and LEDs.
1- Manual Control of ADX using keys and LEDs:
Operating Controls and switching bands:
1- When you power on ADX one of the LED’s will briefly flash 3 times and then another LED will be on solid. The first LED which was flashing 3 times indicates the active or selected BAND bank. By default it is Band1.

For example if the LED was blinking in BAND1 which is 40m band in my ADX now I know my ADX is set for operate on 40m band.
The second LED which is solid is showing the active MODE. For example if it is in FT8 then ADX will operate on 40m in FT8.

So how we will change band?

- Press < --- and --- > switches simultaneously briefly.
- One of the BAND LED will blink 3 times and stay solid. Also TX LED will be on. This doesn’t mean that we are transmitting anything! It is just an indicator to show we are in band switch mode.
- Now using < --- and --- > switches we can turn on LED on different band banks. Of course we need to know which band is assigned to which bank. For that I use labeling tape to label each band bank corresponding to each band setup in the firmware.

See below photo for my band bank labeling as an example!
- After we select the band we would like to operate on, we can exit Band select mode by briefly pressing TX switch. As soon as we press TX switch the TX LED will turn off and the selected band’s LED will flash 3 times to notify us that is the band ADX will operate on. After blinking Band LED turns off, the mode LED will light up showing the mode we are on.
- Now we can scroll between modes with < --- and --- > switches. The on LED is the active mode. We can’t change band by scrolling left or right. This only changes operation mode such as FT8,FT4,JS8 or WSPR. To change band we need to simultaneously press two switches briefly. Then we enter band change mode which is indicated by TX LED on.

- Now the most important thing is not to smoke any finals! When we change a band we need to make sure that band’s LPF band module is plugged on!!!

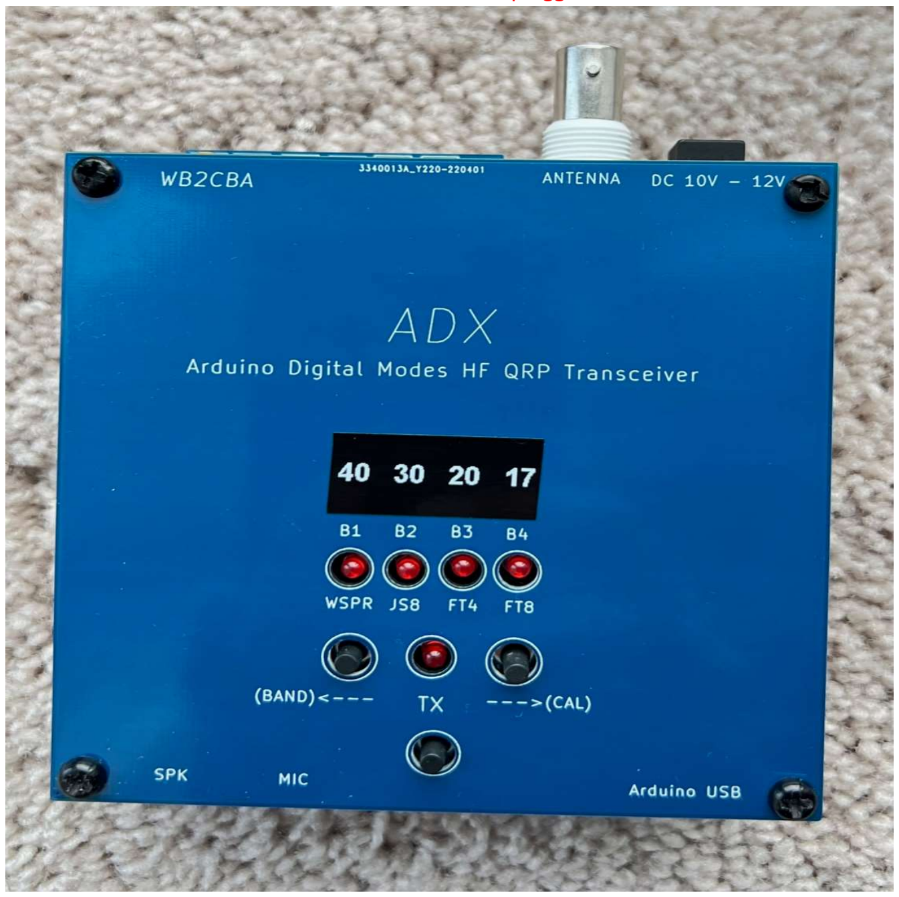
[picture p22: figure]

Connecting ADX Transceiver to Computer and firing up ADX:
1- Connecting ADX Transceiver to any computer is pretty straight forward. We need a MIC which is Microphone input and SPK which is Speaker input or headphone input. We can either use PC built in soundcard or one of those cheap USB Soundcard adapters. I suggest to use a USB soundcard adapter for couple of reasons! This way if anything goes wrong built in soundcard won’t be damaged. Also this will help on ground loop instances.

For USB isolation and peace of mind from ground loop dangers you can use one of these before USB soundcard plug in: https://www.amazon.com/GeeekPi-Isolator-ADUM3160-Isolation-Protection/dp/B07QKYYCD8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 =366402536789&hvpos=&hvnetw=g&hvrand=10336854439692763421&hvqmt=&hvde v=c&hvdvcmdl=&hvlocint=&hvlocphy=9003562&hvtargid=pla-814018215075

For USB soundcard adapter I use this sound card from amazon: https://www.amazon.com/Sabrent-External-Adapter-Windows-AU-MMSA/dp/B00IRVQ0F8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

- We also need 3.5mm audio jack male to 3,5 mm audio jack male extension adapter cables. Actually two of them!
Again from amazon I use this: https://www.amazon.com/Syncwire-Braided-Auxiliary-Adapter-Headphones/dp/B01I0SI1SG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

These are just examples. You can get anything similar to these.

2- Connect Soundcard MIC input to ADX MIC input with one of the 3.5mm audio cables. To do the same connection from soundcard SPK output to ADX SPK input with the other 3.5mm audio cable.
3- Run WSJT/X or JSCALL software.
4- Power on ADX.
5- When you power on ADX one of the LED’s will briefly flash 3 times and then another LED will be on solid. The first LED which was flashing 3 times indicated the active selected BAND bank. So now we know which band we are going to operate on so double check if that LPF Band Module is plugged in and we are good to go! Enjoy ADX with Digital modes similar to any other HF Transceiver you will operate digital modes on!

For setting WSJT/X to work with ADX in Manual Mode:
- Go to Settings/Radio and activate PTT as VOX.
- Choose your soundcard under Settings/Audio menu
- Set Speaker Volume to 100%.
That’s all you need to start working with WSJT/X. This applies pretty much to other software such as JS8Call or WSJT/Z etc.

2- Using ADX in CAT control Mode:
ADX can be controlled with CAT – Computer Aided Transceiver – control too.
In CAT control mode ADX emulates KENWOOD TS2000 Transceiver CAT commands. In CAT control, Frequency and TX/RX of ADX is controlled via CAT commands.
For example in WSJT/X CAT control can change bands, modes and control TX.
To operate on CAT:
- Connect Arduino Nano USB connection to PC USB port.
- Connect Audio jacks to MIC and Speaker of PC and ADX as in Manual mode described above.
Setup Audio in GUI application for your sound card. For example for WSJT/X, go to settings/audio menu and choose audio in and audio out sound card.
For CAT control SETUP:
1- Choose KENWOOD TS2000 as transceiver
2- Choose comm port for your ADX com port from the com port list of your GUI software and set for 9600 bps, 8 data bits and 1 stop bit.

Here is WSJT/X CAT RADIO setup page for ADX as an example:

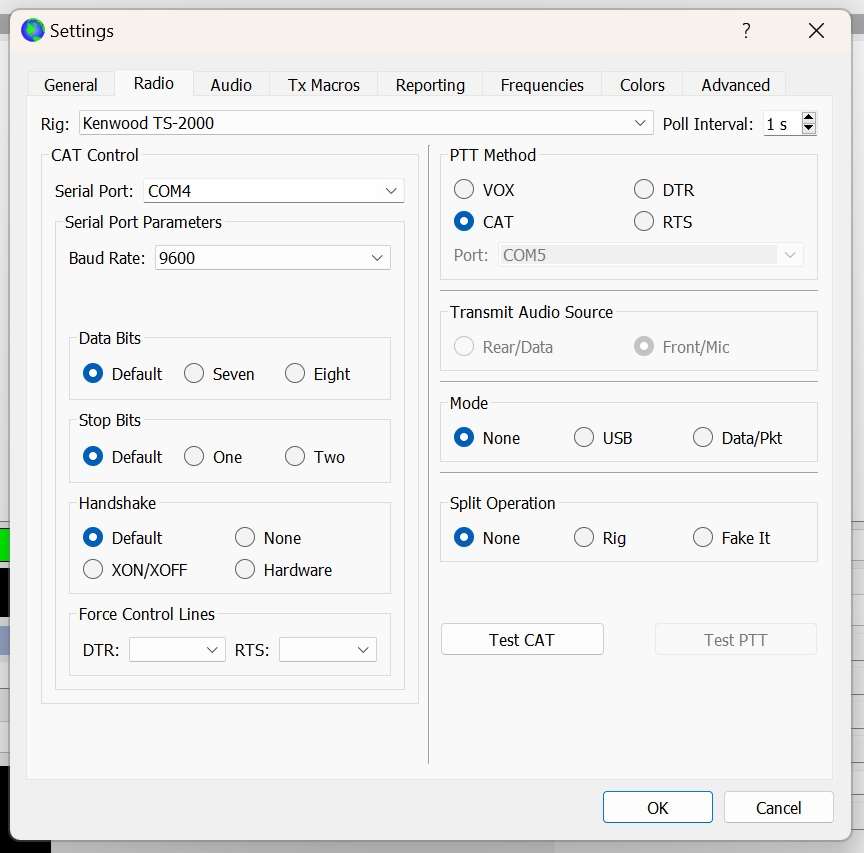
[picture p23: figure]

If all setup is selected right and USB is connected to ADX when Test CAT is pressed after a short pause it should be green. If it is green then CAT is working properly and active.

IMPORTANT POINTS WHEN OPERATING with CAT:
- When operating with CAT any band can be selected without any limitation though the important point is to plug in the right LPF Band filter module on ADX before band change!
If a wrong LPF filter is used for a band that is not matching the selected band with CAT , this can damage BS170 PA mosfets.

- When CAT is active JS8CALL and FT4 LEDS will illuminate and none of those switches or leds will work. Only TX led will be working when TX is on. This manual control lock out is designed on purpose to prevent any conflicting commands between manual mode and CAT.
- CAT Test PTT check button on CAT setup won’t work as ADX does not have a physical PTT control via a pin or button and this is totally normal. ADX PTT is controlled via audio that is transmitted from GUI application like WSJT/X. CAT PTT selection setup can be CAT or VOX and won’t make much difference.
- When ADX is first powered up it starts in Manual control mode with switches and leds as usual. When CAT is activated it automatically enters into CAT mode with default 20m FT8 selected. Make sure to choose the right band and mode before starting TX in accordance with plugged in LPF Band Module.
- When ADX is in CAT mode it will be working only in CAT mode. To exit CAT mode recycle power by brief on/off. Now ADX will start in Manual control mode again.

ADX Limitations and areas that need improvement with wish list! And what is this rig’s purpose in life?
ADX is a simple transceiver that can operate only in digital modes and especially those four popular digital modes, FT8,FT4,JS8Call and WSPR with pin point frequency settings. These are slow tonal modes which Arduino can cope with capturing, decoding and generating FSK signal. Can this rig work on faster digital modes? May be. I am not sure. I haven’t tried but it won’t hurt to experiment with.
The firmware of ADX is basic and there is a lot of room to improve and speed up things. My Arduino programming capabilities are limited as you will witness from the code I put together
Receiver works with reasonable performance for such a simple and dirt cheap receiver design though this is another block that can benefit from improvements. A better band pass filter, an rf amplifier may be a good addition. Currently I am using LPF filter’s first stage band pass which is working pretty good! It’s a cheat! A QSD type RX stage like uSDX’s FST3253 will improve RX sensitivity and most important, selectivity.
An onboard soundcard with a USB onboard hub for Arduino serial might be a nice addition too for single point usb connection control with CAT!
A quad band LPF board with I2C band switching similar to my design uSDX QuadBand LPF board might be another addition which can automate things with a CAT interface!

The wish list goes on and on but it boils down to the same conclusion! I started to tinker with this rig to be a simple and dirt cheap HF transceiver which performs reasonable with minimal hardware to lure young Amateur Radio enthusiasts with a Geek mindset and DIY knack to Amateur Radio and digital modes. I think ADX is hitting all these bullet points as a beginner HF Transceiver. Any of these additions will blow the main purpose of existence of this simple HF digital modes transceiver. So I leave that evaluation to you…
My hope and wish is that this simple HF Transceiver to serve its purpose and attract young hams to Amateur Radio Hobby and DIY Amateur Radio community.
Acknowledgments:
I would like to thank:
- Burkhard Kainka, DK7JD for his inspirational Audio FSK generation code for Arduino. Without it I would be still scratching my head how to solve this problem!
- Jason Mildrum, NT7S for his excellent SI5351 Arduino Library.
- ADX CAT code inspired from Lajos Höss, HA8HL TS2000 CAT implementation for Arduino.
- Improved FSK TX signal generation code of JE1RAV
- Joerg Frede, DK3JF for his contribution for cleaning up my initial ADX code and transforming it into a pro code which is now is the official ADX firmware.

Last word: No usage restrictions or silly licenses on this design. This is a Free and Open Source design for the ham community. Feel free to use in any means including commercial usage. Sky is the limit!
Enjoy your Digital QSOs!
Barbaros Asuroglu aka Barb, WB2CBA
06/10/2023
wb2cba@gmail.com

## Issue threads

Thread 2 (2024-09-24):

CAT Control not working

emm312, 2024-09-24:
Hi all,

I tried cat control this evening but I got an error:
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
My settings look correct, perhaps there was some update in hamlib that isn't in the ADX firmware yet.

73s de Emmanuel

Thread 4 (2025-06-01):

>CPL file

MachinistEt1964, 2025-06-01:
Hello, i am not so good with the project i think so i want to order the pcb at jlcpcb.
But, it seems i need a .cpl file, but i can't find it and i don't know how to make it??
Regards
Rene
PD0REB

WB2CBA, 2025-06-02:
Rene you don't need .CPL file for getting ADX pcb manufactured. Just submit gerber file as zip file and it will work. JLCPCB accepts ADX gerber file as .zip file

WB2CBA, 2025-06-02:
Rene,

Do not unzip gerber file. Upload as .zip file.

MachinistEt1964, 2025-06-02:
Hello mister Barb, i did that right but by uploading the bom file its okay,
but what .CPL file, also the bom file or is this different?
Regards
Rene
PD0REB

Op ma 2 jun 2025 om 17:26 schreef Barb - WB2CBA ***@***.***>:

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

--
Groetjes,
Rene van Berkel

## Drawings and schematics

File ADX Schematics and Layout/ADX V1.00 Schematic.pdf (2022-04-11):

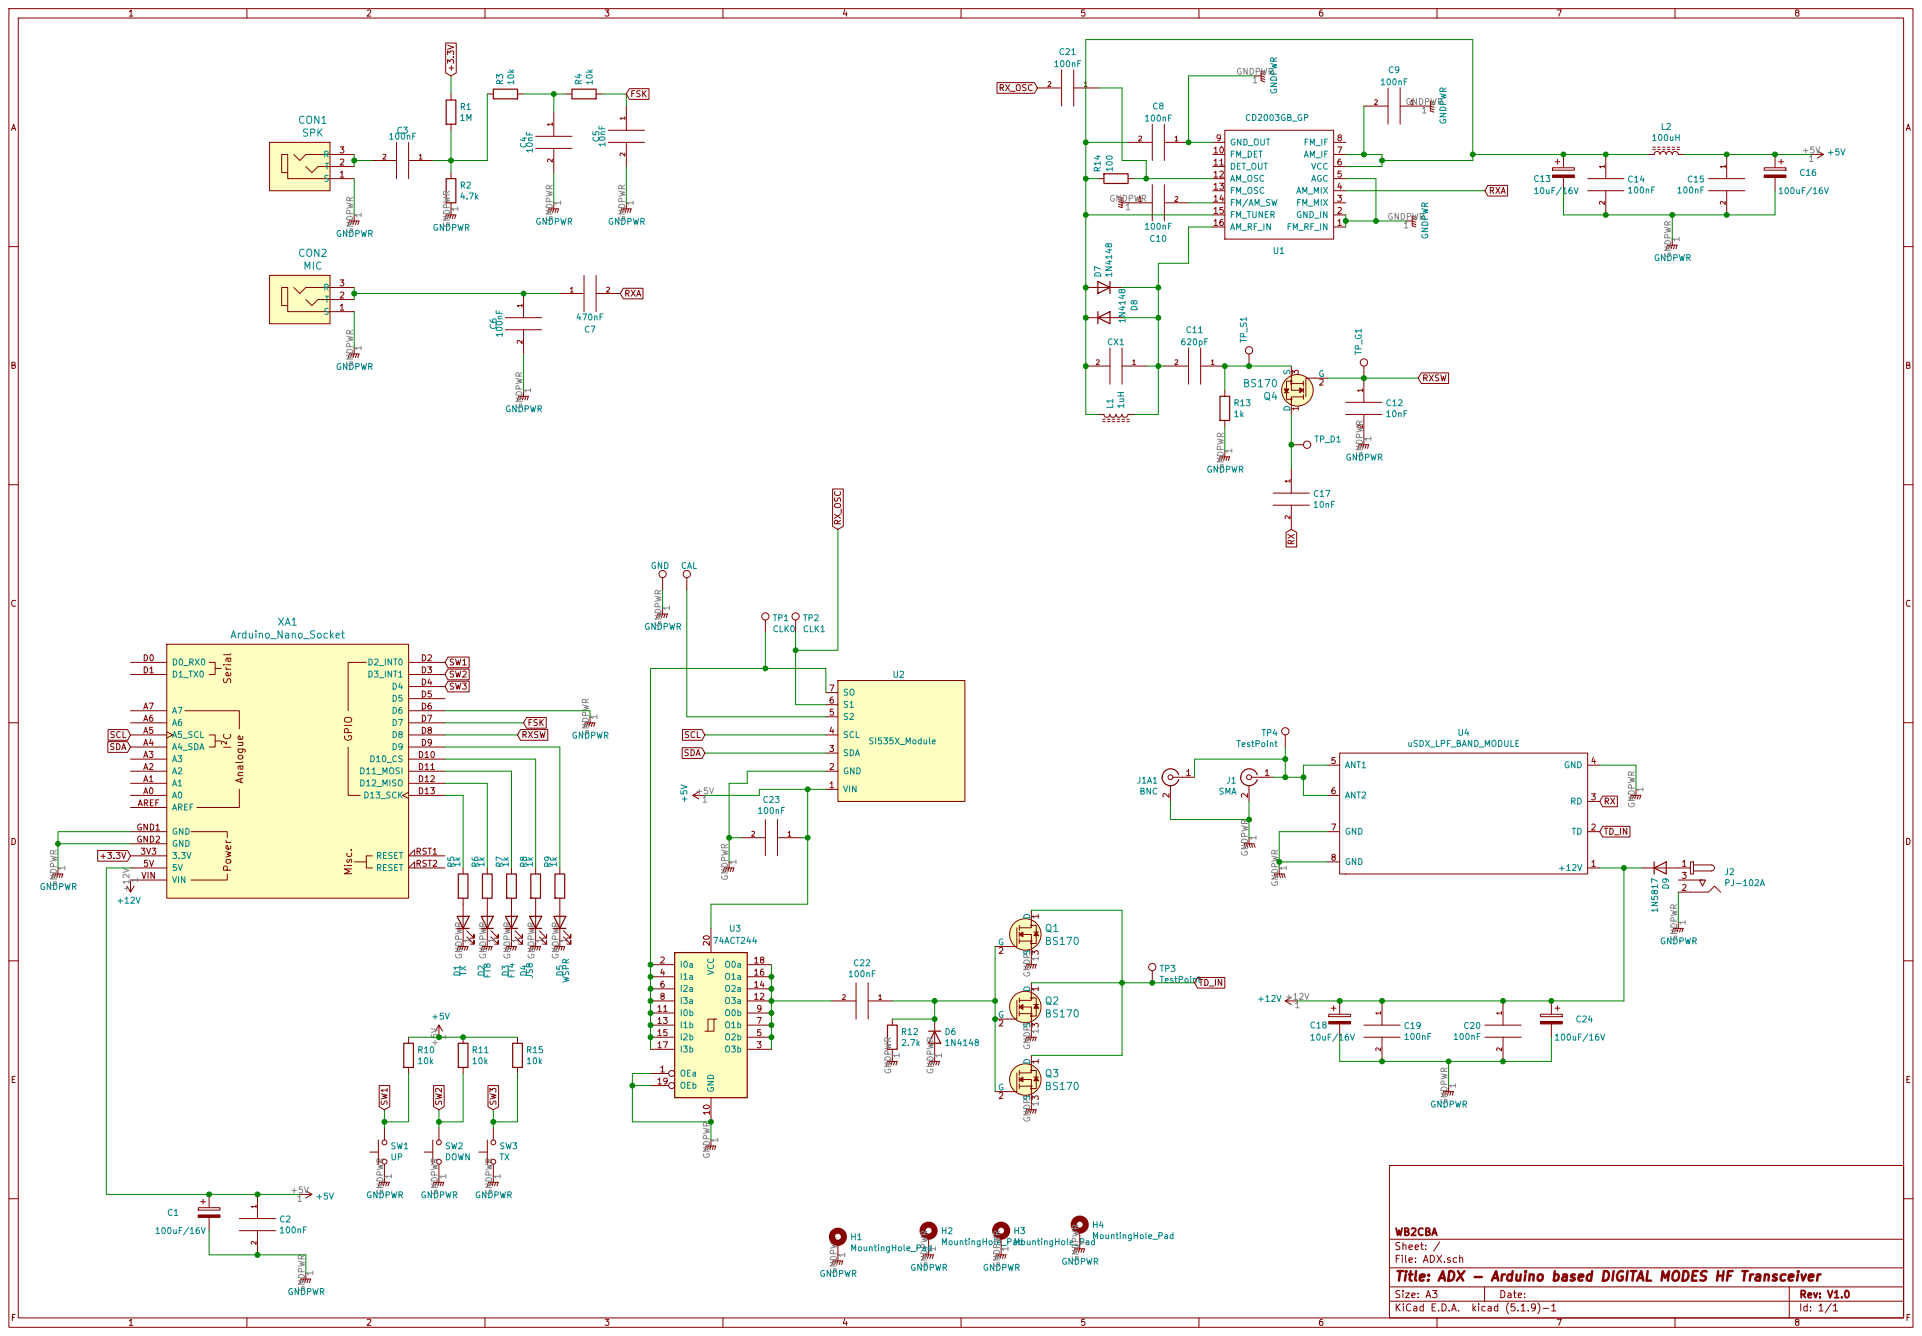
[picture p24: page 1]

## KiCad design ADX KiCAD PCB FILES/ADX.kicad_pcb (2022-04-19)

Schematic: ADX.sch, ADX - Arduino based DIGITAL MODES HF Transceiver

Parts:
C1, C16, C24: 100uF/16V; CP_Radial_D5.0mm_P2.50mm
C2, C3, C6, C8, C9, C10, C14, C15, C19, C20, C21, C22, C23: 100nF; C_Disc_D3.0mm_W1.6mm_P2.50mm
C4, C5: 10nF; C_Disc_D3.0mm_W1.6mm_P2.50mm
C7: 470nF; C_Disc_D3.0mm_W1.6mm_P2.50mm
C11: 620pF; C_Disc_D3.0mm_W1.6mm_P2.50mm
C12, C17: 10nF; C_Disc_D3.0mm_W2.0mm_P2.50mm
C13, C18: 10uF/16V; CP_Radial_D5.0mm_P2.50mm
CON1: SPK; Headphone_Jack_3.5mm_SJ1-3523N; MPN SJ1-3523N; Digi-Key_PN CP1-3523N-ND
CON2: MIC; Headphone_Jack_3.5mm_SJ1-3523N; MPN SJ1-3523N; Digi-Key_PN CP1-3523N-ND
CX1: C_Disc_D3.0mm_W1.6mm_P2.50mm
D1: TX; LED_D3.0mm
D2: FT8; LED_D3.0mm
D3: FT4; LED_D3.0mm
D4: JS8; LED_D3.0mm
D5: WSPR; LED_D3.0mm
D6: 1N4148; D_A-405_P2.54mm_Vertical_AnodeUp
D7, D8: 1N4148; D_A-405_P2.54mm_Vertical_KathodeUp
D9: 1N5817; D_A-405_P2.54mm_Vertical_KathodeUp
GND1: TestPoint_THTPad_2.0x2.0mm_Drill1.0mm
H1, H2, H3, H4: MountingHole_Pad; MountingHole_3.2mm_M3_ISO7380_Pad
J1: SMA; SMA_Samtec_SMA-J-P-X-ST-EM1_EdgeMount
J1A1: BNC; BNC_Amphenol_B6252HB-NPP3G-50_Horizontal
J2: PJ-102A; Barrel_Jack_5.5mmODx2.1mmID_PJ-102A; MPN PJ-102A; Digi-Key_PN CP-102A-ND
L1: 1uH; L_Toroid_Vertical_L10.0mm_W5.0mm_P5.08mm
L2: 100uH; R_Axial_DIN0204_L3.6mm_D1.6mm_P2.54mm_Vertical
Q1, Q2, Q3: BS170; TO-92_HandSolder; MPN BS170; Digi-Key_PN BS170-ND
Q4: BS170; TO-92L_HandSolder; MPN BS170; Digi-Key_PN BS170-ND
R1: 1M; R_Axial_DIN0204_L3.6mm_D1.6mm_P1.90mm_Vertical
R2: 4.7k; R_Axial_DIN0204_L3.6mm_D1.6mm_P1.90mm_Vertical
R3, R4, R10, R11, R15: 10k; R_Axial_DIN0204_L3.6mm_D1.6mm_P1.90mm_Vertical
R5, R6, R7, R8, R9, R13: 1k; R_Axial_DIN0204_L3.6mm_D1.6mm_P1.90mm_Vertical
R12: 2.7k; R_Axial_DIN0204_L3.6mm_D1.6mm_P1.90mm_Vertical
R14: 100; R_Axial_DIN0204_L3.6mm_D1.6mm_P1.90mm_Vertical
SW1: UP(BAND); SW_PUSH_6mm
SW2: DOWN(CAL); SW_PUSH_6mm
SW3: TX; SW_PUSH_6mm
TP1: CLK0; TestPoint_THTPad_2.0x2.0mm_Drill1.0mm
TP2: CLK1; TestPoint_THTPad_2.0x2.0mm_Drill1.0mm
TP3, TP4: TestPoint; TestPoint_THTPad_2.0x2.0mm_Drill1.0mm
TP7: GND; TestPoint_THTPad_2.0x2.0mm_Drill1.0mm
TP8: CAL; TestPoint_THTPad_2.0x2.0mm_Drill1.0mm
TP_D1: TestPoint_THTPad_1.0x1.0mm_Drill0.5mm
TP_G1: TestPoint_THTPad_1.0x1.0mm_Drill0.5mm
TP_S1: TestPoint_THTPad_1.0x1.0mm_Drill0.5mm
U1: CD2003GB_GP; DIP-16_W7.62mm_Socket_LongPads
U2: SI535X_Module; SI5351 Module_Vertical
U3: 74ACT244; DIP-20_W7.62mm_LongPads
U4: uSDX_LPF_BAND_MODULE; uSDX_LPF_Band_Module
XA1: Arduino_Nano_Socket

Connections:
+3.3V: R1.1, XA1.3V3 (3.3V)
+5V: C1.1, C2.1, C15.1, C16.1, C23.1, L2.1, R10.1, R11.1, R15.1, U2.1 (VIN), U3.20 (VCC), XA1.5V
+12V: C18.1, C19.1, C20.1, C24.1, D9.1 (K), U4.1 (+12V), XA1.VIN
FSK: C5.1, R4.2, XA1.D7
GNDPWR: C1.2, C2.2, C4.2, C5.2, C6.2, C8.1, C9.1, C10.1, C12.2, C13.2, C14.2, C15.2, C16.2, C18.2, C19.2, C20.2, C23.2, C24.2, CON1.1 (S), CON2.1 (S), D1.1 (K), D2.1 (K), D3.1 (K), D4.1 (K), D5.1 (K), D6.2 (A), GND1.1, H1.1, H2.1, H3.1, H4.1, J1.2 (Ext), J1A1.2 (Ext), J2.2, Q1.3 (S), Q2.3 (S), Q3.3 (S), R2.2, R12.2, R13.2, SW1.1, SW2.1, SW3.1, TP7.1, U1.1, U1.2, U1.5, U1.9, U2.2 (GND), U3.1 (OEa), U3.10 (GND), U3.19 (OEb), U4.4 (GND), U4.7 (GND), U4.8 (GND), XA1.D6, XA1.GND1 (GND), XA1.GND2 (GND)
unnamed: C3.1, R1.2, R2.1, R3.1
unnamed: C3.2, CON1.2 (T), CON1.3 (R)
unnamed: C4.1, R3.2, R4.1
unnamed: C6.1, C7.1, CON2.2 (T), CON2.3 (R)
unnamed: C10.2, U1.14
unnamed: C11.1, Q4.3 (S), R13.1, TP_S1.1
unnamed: C11.2, CX1.1, D7.1 (K), D8.2 (A), L1.1, U1.16
unnamed: C8.2, C9.2, C13.1, C14.1, CX1.2, D7.2 (A), D8.1 (K), L1.2, L2.2, R14.2, U1.6, U1.7, U1.15
unnamed: C17.1, Q4.1 (D), TP_D1.1
unnamed: C21.1, R14.1, U1.12
unnamed: C22.1, D6.1 (K), Q1.2 (G), Q2.2 (G), Q3.2 (G), R12.1
unnamed: C22.2, U3.3 (O3b), U3.5 (O2b), U3.7 (O1b), U3.9 (O0b), U3.12 (O3a), U3.14 (O2a), U3.16 (O1a), U3.18 (O0a)
unnamed: D1.2 (A), R5.2
unnamed: D2.2 (A), R6.2
unnamed: D3.2 (A), R7.2
unnamed: D4.2 (A), R8.2
unnamed: D5.2 (A), R9.2
unnamed: D9.2 (A), J2.1
unnamed: J1.1 (In), J1A1.1 (In), TP4.1, U4.5 (ANT1), U4.6 (ANT2)
unnamed: R5.1, XA1.D13 (D13_SCK)
unnamed: R6.1, XA1.D12 (D12_MISO)
unnamed: R7.1, XA1.D11 (D11_MOSI)
unnamed: R8.1, XA1.D10 (D10_CS)
unnamed: R9.1, XA1.D9
unnamed: TP1.1, U2.7 (SO), U3.2 (I0a), U3.4 (I1a), U3.6 (I2a), U3.8 (I3a), U3.11 (I0b), U3.13 (I1b), U3.15 (I2b), U3.17 (I3b)
unnamed: TP8.1, U2.5 (S2)
RX: C17.2, U4.3 (RD)
RXA: C7.2, U1.4
RXSW: C12.1, Q4.2 (G), TP_G1.1, XA1.D8
RX_OSC: C21.2, TP2.1, U2.6 (S1)
SCL: U2.4 (SCL), XA1.A5 (A5_SCL)
SDA: U2.3 (SDA), XA1.A4 (A4_SDA)
SW1: R10.2, SW1.2, XA1.D2 (D2_INT0)
SW2: R11.2, SW2.2, XA1.D3 (D3_INT1)
SW3: R15.2, SW3.2, XA1.D4
TD_IN: Q1.1 (D), Q2.1 (D), Q3.1 (D), TP3.1, U4.2 (TD)

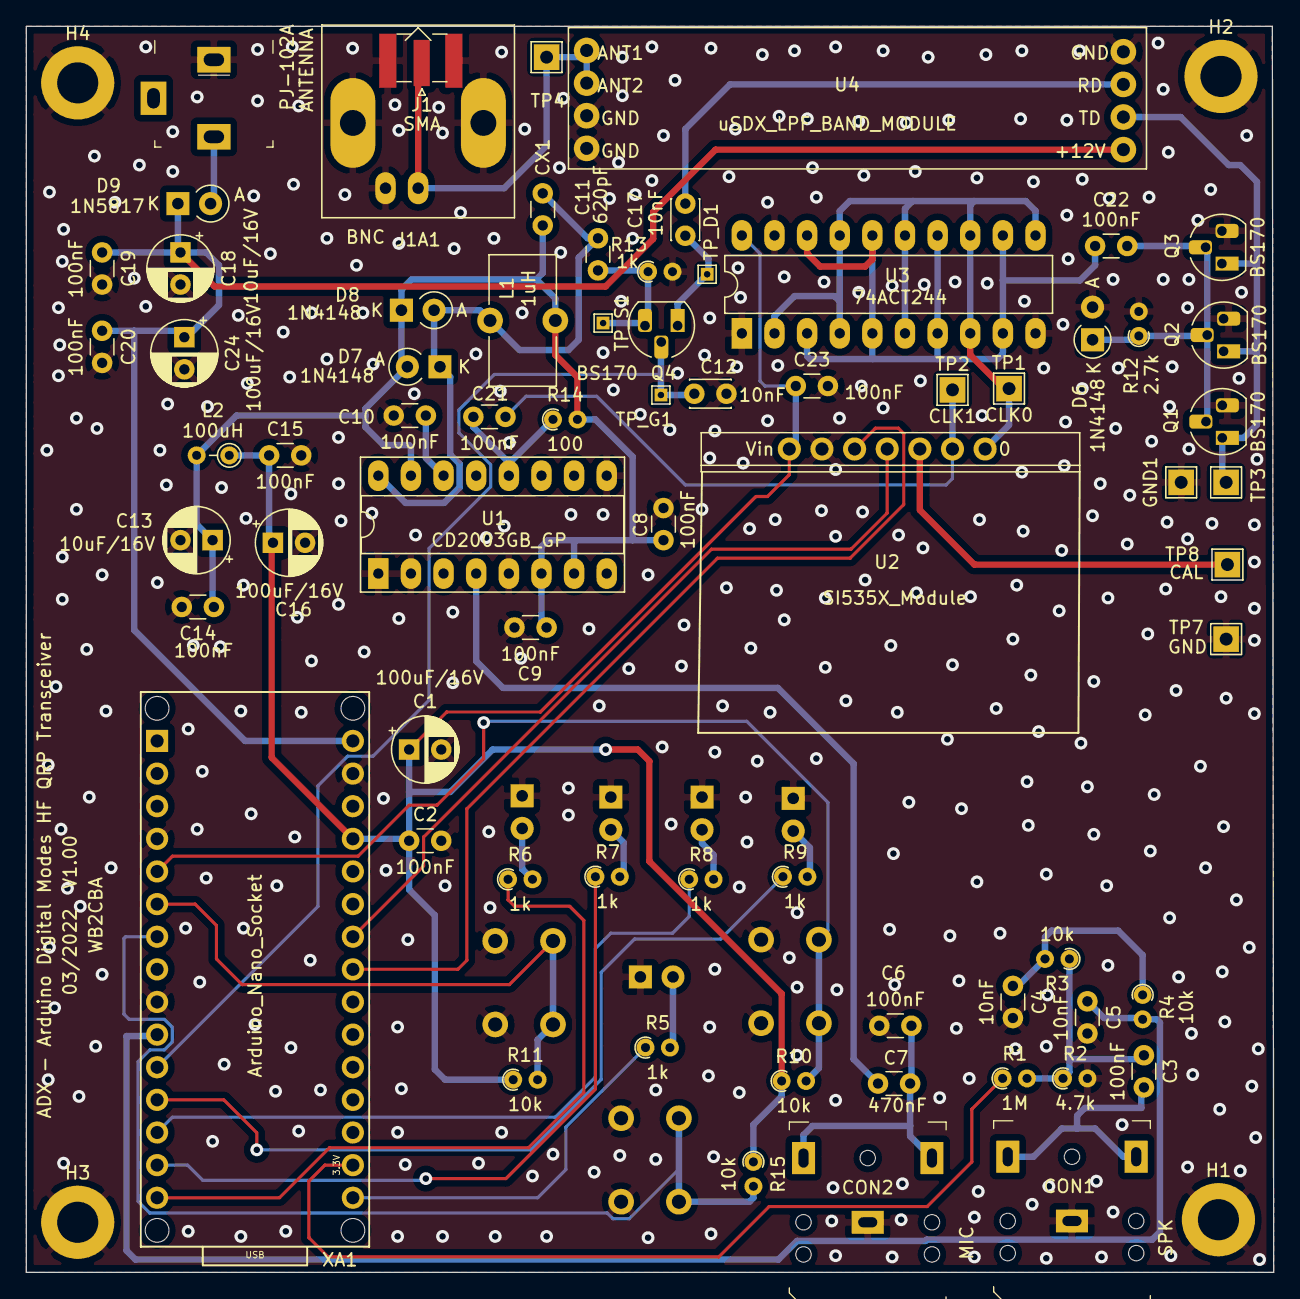
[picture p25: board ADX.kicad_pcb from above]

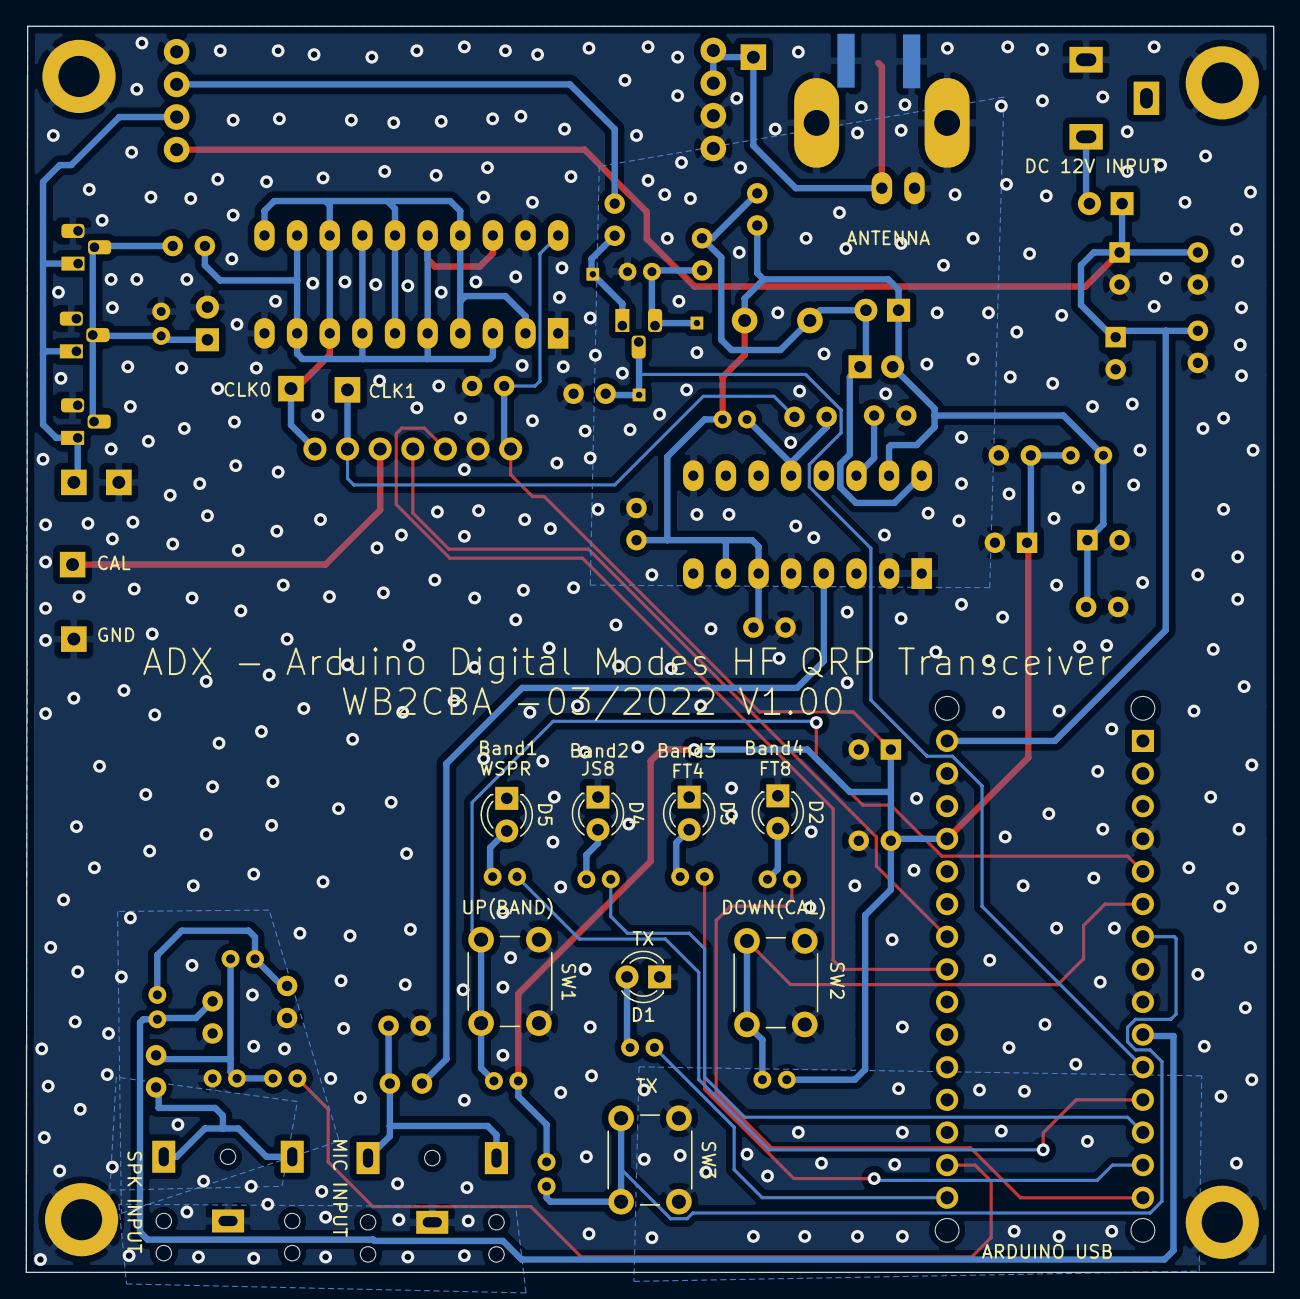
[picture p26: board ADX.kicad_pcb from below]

Board: 2 copper layers, 97.1 x 97.0 mm, 82 parts (8 on the bottom side), 41 nets.

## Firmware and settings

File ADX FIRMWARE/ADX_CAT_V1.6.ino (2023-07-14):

//*********************************************************************************************************
//******************* ADX  - ARDUINO DIGITAL MODES HF TRANSCEIVER WITH CAT CONTROL  ***********************
//********************************* Write up start: 02/01/2022 ********************************************
// FW VERSION: ADX_CAT_V1.6 - Version release date: 07/14/2023
// Barb(Barbaros ASUROGLU) - WB2CBA - 2022
//  Version History
//  V1.0  Modified Calibration EEPROM to protect R/W cycle of EEPROM.
//  V1.1 10m/28Mhz band support added.
//  V1.2 CAT Control and JE1RAV improved FSK TX code fixing less than 500 Hz TX error correction added.
//  V1.4 Serial timeout delay change. 
//  V1.5 Cleanup Code by Joerg Frede - DK3JF - 2023
//  V1.6 Band change display Bug correction - Thanks to KD5RXT and LA7WRA for reporting this issue.
//*********************************************************************************************************
// Required Libraries
// ----------------------------------------------------------------------------------------------------------------------
// Etherkit Si5351 (Needs to be installed via Library Manager to arduino ide) - SI5351 Library by Jason Mildrum (NT7S) - https://github.com/etherkit/Si5351Arduino
// Arduino "Wire.h" I2C library(built-into arduino ide)
// Arduino "EEPROM.h" EEPROM Library(built-into arduino ide)
//*************************************[ LICENCE and CREDITS ]*********************************************
//  Initial FSK TX Signal Generation code by: Burkhard Kainka(DK7JD) - http://elektronik-labor.de/HF/SDRtxFSK2.html
//  SI5351 Library by Jason Mildrum (NT7S) - https://github.com/etherkit/Si5351Arduino
//  ADX CAT code inspired from Lajos Höss, HA8HL TS2000 CAT implementation for Arduino.
//  Improved FSK TX  signal generation code is from JE1RAV https://github.com/je1rav/QP-7C
//
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
//*****************[ SI5351 VFO CALIBRATION PROCEDURE ]****************************************
// For SI5351 VFO Calibration Procedure follow these steps:
// 1 - Connect CAL test point and GND test point on ADX PCB to a Frequency meter or Scope that can measure 1 Mhz up to 1Hz accurately.
// 2 - Press SW2 / --->(CAL) pushbutton and hold.
// 4 - Power up with 12V or with 5V by using arduino USB socket while still pressing SW2 / --->(CAL) pushbutton.
// 5 - FT8 and WSPR LEDs will flash 3 times and stay lit. Now Release SW2 / --->(CAL). Now Calibration mode is active.
// 6 - Using SW1(<---) and SW2(--->) pushbuttons change the Calibration frequency.
// 7 - Try to read 1 Mhz = 1000000 Hz exact on  Frequency counter or Oscilloscope.
//     The waveform is Square wave so freqency calculation can be performed esaily.
// 8 - If you read as accurate as possible 1000000 Hz then calibration is done.
// 9 - Now we must save this calibration value to EEPROM location.
//     In order to save calibration value, press TX button briefly. TX LED will flash 3 times which indicates that Calibration value is saved.
//
//********************************[ CAT CONTROL SETTINGS and CAT Functionality ]********************
// CAT CONTROL RIG EMULATION: KENWOOD TS2000
// SERIAL PORT SETTINGS: 9600 baud,8 bit,1 stop bit
// When CAT is active FT4 and JS8 leds will be solid lit.
// In CAT mode none of the Switches and leds are active including TX SWITCH in order to avoid different setting clashes except TX LED.
// TX LED WILL BE LIT briefly on/off and then solid during TX WHEN TRANSMITTING IN CAT Mode.
// In CAT mode ADX can be controlled ONLY by CAT interface. Frequency and TX can be controlled via CAT.
// To get out of CAT mode and to use ADX with Switch and led interface just recycle power. Once activated CAT mode stays active as rig control Until power recycle.
// In CAT mode manual Band setup is deactivated and ADX can be operated on any band as long as the right lpf filter module is plugged in.
// IN CAT MODE MAKE SURE THE CORRECT LPF MODULE IS PLUGGED IN WHEN OPERATING BAND IS CHANGED!!! IF WRONG LPF FILTER MODULE IS PLUGGED IN then PA POWER MOSFETS CAN BE DAMAGED!

//*******************************[ LIBRARIES ]*************************************************
#include <si5351.h>
#include "Wire.h"
#include <EEPROM.h>
//*******************************[ VARIABLE DECLERATIONS ]*************************************
unsigned int temp = 0;
unsigned int mode = 0;
unsigned int Band_slot = 0;
unsigned int Band = 0;
unsigned int Bdly = 250;  // Blick delay

boolean TX_State = 0;
boolean UP_State = 0;
boolean DOWN_State = 0;
boolean TXSW_State = 0;

unsigned long freq = 0;
unsigned long cal_factor = 0;
unsigned long Cal_freq = 1000000UL; // Calibration Frequency: 1 Mhz = 1000000 Hz
unsigned long F_FT8;
unsigned long F_FT4;
unsigned long F_JS8;
unsigned long F_WSPR;

//------------ CAT Variables
boolean cat_stat = 0;
boolean TxStatus = 0; //0 =  RX 1=TX
unsigned int CAT_mode = 2;
String received;
String receivedPart1;
String receivedPart2;
String command;
String command2;
String parameter;
String parameter2;
String sent;
String sent2;

// **********************************[ DEFINE's ]***********************************************
#define UP    2 // UP Switch
#define DOWN  3 // DOWN Switch
#define TXSW  4 // TX Switch
#define RX    8 // RX SWITCH
#define TX   13 // TX LED
#define WSPR  9 // WSPR LED
#define JS8  10 // JS8 LED
#define FT4  11 // FT4 LED
#define FT8  12 // FT8 LED

#define SI5351_REF     25000000UL  //change this to the frequency of the crystal on your si5351’s PCB, usually 25 or 27 MHz

//**********************************[ BAND SELECT ]************************************************
// ADX can support up to 4 bands on board. Those 4 bands needs to be assigned to Band1 ... Band4 from supported 6 bands.
// To change bands press SW1 and SW2 simultaneously. Band LED will flash 3 times briefly and stay lit for the stored band. also TX LED will be lit to indicate
// that Band select mode is active. Now change band bank by pressing SW1(<---) or SW2(--->). When desired band bank is selected press TX button briefly to exit band select mode.
// Now the new selected band bank will flash 3 times and then stored mode LED will be lit.
// TX won't activate when changing bands so don't worry on pressing TX button when changing bands in band mode.

// Assign your prefered bands to B1,B2,B3 and B4
// Supported Bands are: 80m, 40m, 30m, 20m,17m, 15m

unsigned int Band1 = 40; // Band 1 // These are my default bands. Feel free to swap with yours
unsigned int Band2 = 30; // Band 2
unsigned int Band3 = 20; // Band 3
unsigned int Band4 = 17; // Band 4

Si5351 si5351;

//*************************************[ SETUP FUNCTION ]**************************************
void setup() {
  pinMode(UP, INPUT);
  pinMode(DOWN, INPUT);
  pinMode(TXSW, INPUT);
  pinMode(TX, OUTPUT);
  pinMode(WSPR, OUTPUT);
  pinMode(JS8, OUTPUT);
  pinMode(FT4, OUTPUT);
  pinMode(FT8, OUTPUT);
  pinMode(RX, OUTPUT);
  pinMode(7, INPUT); //PD7 = AN1 = HiZ, PD6 = AN0 = 0

  //SET UP SERIAL FOR CAT CONTROL

  Serial.begin(9600);
  Serial.setTimeout(4);
  
  INIT(); // Get data from EEprom

  //------------------------------- SET SI5351 VFO -----------------------------------
  // The crystal load value needs to match in order to have an accurate calibration
  si5351.init(SI5351_CRYSTAL_LOAD_8PF, 0, 0);
  si5351.set_correction(cal_factor, SI5351_PLL_INPUT_XO);
  si5351.set_pll(SI5351_PLL_FIXED, SI5351_PLLA);
  si5351.drive_strength(SI5351_CLK0, SI5351_DRIVE_8MA); // SET For Max Power
  si5351.drive_strength(SI5351_CLK1, SI5351_DRIVE_2MA); // Set for reduced power for RX
  si5351.drive_strength(SI5351_CLK2, SI5351_DRIVE_2MA); // Set for lower power for calibration
  si5351.set_clock_pwr(SI5351_CLK2, 0); // Turn off Calibration Clock

  if ( digitalRead(DOWN) == LOW ) {
    Calibration();
  }

  TCCR1A = 0x00;
  TCCR1B = 0x01; // Timer1 Timer 16 MHz
  TCCR1B = 0x81; // Timer1 Input Capture Noise Canceller
  ACSR |= (1<<ACIC);  // Analog Comparator Capture Input

  digitalWrite(RX,LOW);

  Band_assign();
  Freq_assign();
  Mode_assign();
}

//**************************[ END OF SETUP FUNCTION ]************************

//***************************[ Main LOOP Function ]**************************
void loop() {
  // CAT CHECK SERIAL FOR NEW DATA FROM WSJT-X AND RESPOND TO QUERIES

  if ((Serial.available() > 0) || (cat_stat == 1)) {
    cat_stat = 1;
    CAT_control();
    si5351.set_freq(freq * 100ULL, SI5351_CLK1);
    si5351.output_enable(SI5351_CLK1, 1);   //RX on
    digitalWrite(WSPR, LOW);
    digitalWrite(JS8, HIGH);
    digitalWrite(FT4, HIGH);
    digitalWrite(FT8, LOW);
  }
  else {  
    UP_State = digitalRead(UP);
    DOWN_State = digitalRead(DOWN);

    if ((UP_State == LOW) && (DOWN_State == LOW) && (TX_State == 0)) {
      delay(100);
      UP_State = digitalRead(UP);
      DOWN_State = digitalRead(DOWN);
      if ((UP_State == LOW) && (DOWN_State == LOW) && (TX_State == 0)) {
        Band_Select();
      }
    }

    if ((UP_State == LOW) && (DOWN_State == HIGH) && (TX_State == 0)) {
      delay(100);
      UP_State = digitalRead(UP);
      DOWN_State = digitalRead(DOWN);
      if ((UP_State == LOW) && (DOWN_State == HIGH) && (TX_State == 0)) {
        mode = mode - 1;
        if (mode < 1) {
          mode = 4;
        }
        EEPROM.put(40, mode);
        Mode_assign();
      }
    }

    UP_State = digitalRead(UP);
    DOWN_State = digitalRead(DOWN);

    if ((UP_State == HIGH) && (DOWN_State == LOW) && (TX_State == 0)) {
      delay(100);
      UP_State = digitalRead(UP);
      DOWN_State = digitalRead(DOWN);
      if ((UP_State == HIGH) && (DOWN_State == LOW) && (TX_State == 0)) {
        mode = mode + 1;
        if (mode > 4){
          mode = 1;
        }
        EEPROM.put(40, mode);
        Mode_assign();
      }
    }
  }
  
  TXSW_State = digitalRead(TXSW);

  if ((TXSW_State == LOW) && (TX_State == 0)) {
    delay(100);
    TXSW_State = digitalRead(TXSW);
    if ((TXSW_State == LOW) && (TX_State == 0)) {
      Mode_assign();
      ManualTX();
    }
  }

  // The following code is from JE1RAV https://github.com/je1rav/QP-7C
  //(Using 3 cycles for timer sampling to improve the precision of frequency measurements)
  //(Against overflow in low frequency measurements)

  int FSK = 1;
  int FSKtx = 0;

  while (FSK>0) {
    int Nsignal = 10;
    int Ncycle01 = 0;
    int Ncycle12 = 0;
    int Ncycle23 = 0;
    int Ncycle34 = 0;
    unsigned int d1=1,d2=2,d3=3,d4=4;

    TCNT1 = 0;
    while (ACSR &(1<<ACO)) {
      if (TIFR1&(1<<TOV1)) {
        Nsignal--;
        TIFR1 = _BV(TOV1);
        if (Nsignal <= 0) {
          break;
        }
      }
    }
    while ((ACSR &(1<<ACO))==0) {
      if (TIFR1&(1<<TOV1)) {
        Nsignal--;
        TIFR1 = _BV(TOV1);
        if (Nsignal <= 0) {
          break;
        }
      }
    }
    if (Nsignal <= 0) {
      break;
    }
    TCNT1 = 0;
    while (ACSR &(1<<ACO)) {
        if (TIFR1&(1<<TOV1)) {
        Ncycle01++;
        TIFR1 = _BV(TOV1);
        if (Ncycle01 >= 2) {
          break;
        }
      }
    }
    d1 = ICR1;
    while ((ACSR &(1<<ACO))==0) {
      if (TIFR1&(1<<TOV1)) {
        Ncycle12++;
        TIFR1 = _BV(TOV1);
        if (Ncycle12 >= 3) {
          break;
        }
      }
    }
    while (ACSR &(1<<ACO)) {
      if (TIFR1&(1<<TOV1)) {
        Ncycle12++;
        TIFR1 = _BV(TOV1);
        if (Ncycle12 >= 6) {
          break;
        }
      }
    }
    d2 = ICR1;
    while ((ACSR &(1<<ACO))==0) {
      if (TIFR1&(1<<TOV1)) {
        Ncycle23++;
        TIFR1 = _BV(TOV1);
        if (Ncycle23 >= 3) {
          break;
        }
      }
    }
    while (ACSR &(1<<ACO)) {
      if (TIFR1&(1<<TOV1)) {
        Ncycle23++;
        TIFR1 = _BV(TOV1);
        if (Ncycle23 >= 6) {
          break;
        }
      }
    }
    d3 = ICR1;
    while ((ACSR &(1<<ACO))==0) {
      if (TIFR1&(1<<TOV1)) {
        Ncycle34++;
        TIFR1 = _BV(TOV1);
        if (Ncycle34 >= 3) {
          break;
        }
      }
    }
    while (ACSR &(1<<ACO)) {
      if (TIFR1&(1<<TOV1)) {
        Ncycle34++;
        TIFR1 = _BV(TOV1);
        if (Ncycle34 >= 6) {
          break;
        }
      }
    }
    d4 = ICR1;
    unsigned long codefreq1 = 1600000000/(65536*Ncycle12+d2-d1);
    unsigned long codefreq2 = 1600000000/(65536*Ncycle23+d3-d2);
    unsigned long codefreq3 = 1600000000/(65536*Ncycle34+d4-d3);
    unsigned long codefreq = (codefreq1 + codefreq2 + codefreq3)/3;
    if (d3==d4) codefreq = 5000;
    if ((codefreq < 310000) && (codefreq >= 10000)) {   // Frequency between 100 Hz and 3100 Hz
      if (FSKtx == 0) {
        TX_State = 1;
        digitalWrite(RX,LOW);
        digitalWrite(TX,HIGH);
        delay(10);
        si5351.output_enable(SI5351_CLK1, 0);   // RX off
        si5351.output_enable(SI5351_CLK0, 1);   // TX on
      }
      si5351.set_freq((freq * 100ULL + codefreq), SI5351_CLK0);
      if (cat_stat == 1) CAT_control();
      FSKtx = 1;
    }
    else {
      FSK--;
    }
  }

  digitalWrite(TX,LOW);

  si5351.output_enable(SI5351_CLK0, 0);   // TX off
  si5351.set_freq(freq * 100ULL, SI5351_CLK1);
  si5351.output_enable(SI5351_CLK1, 1);   // RX on
  TX_State = 0;
  digitalWrite(RX,HIGH);
  FSKtx = 0;
}

//*********************[ END OF MAIN LOOP FUNCTION ]*************************

//********************************************************************************
//******************************** [ FUNCTIONS ] *********************************
//********************************************************************************


//************************************[ MODE Assign ]**********************************

void Mode_assign() {

  EEPROM.get(40, mode);

  switch(mode) {
    case 1:
      freq = F_WSPR;
      digitalWrite(WSPR, HIGH);
      digitalWrite(JS8, LOW);
      digitalWrite(FT4, LOW);
      digitalWrite(FT8, LOW);
      break;
    case 2:
      freq = F_JS8;
      digitalWrite(WSPR, LOW);
      digitalWrite(JS8, HIGH);
      digitalWrite(FT4, LOW);
      digitalWrite(FT8, LOW);
      break;
    case 3:
      freq = F_FT4;
      digitalWrite(WSPR, LOW);
      digitalWrite(JS8, LOW);
      digitalWrite(FT4, HIGH);
      digitalWrite(FT8, LOW);
      break;
    case 4:
      freq = F_FT8;
      digitalWrite(WSPR, LOW);
      digitalWrite(JS8, LOW);
      digitalWrite(FT4, LOW);
      digitalWrite(FT8, HIGH);
      break;
  }
}

//********************************[ END OF MODE ASSIGN ]*******************************

//*********************[ Band dependent Frequency Assign Function ]********************
void Freq_assign() {

  switch (Band) {
    case 80:
      F_FT8 = 3573000;
      F_FT4 = 3575000;
      F_JS8 = 3578000;
      F_WSPR = 3568600;
      break;
    case 40:
      F_FT8 = 7074000;
      F_FT4 = 7047500;
      F_JS8 = 7078000;
      F_WSPR = 7038600;
      break;
    case 30:
      F_FT8 = 10136000;
      F_FT4 = 10140000;
      F_JS8 = 10130000;
      F_WSPR = 10138700;
      break;
    case 20:
      F_FT8 = 14074000;
      F_FT4 = 14080000;
      F_JS8 = 14078000;
      F_WSPR = 14095600;
      break;
    case 17:
      F_FT8 = 18100000;
      F_FT4 = 18104000;
      F_JS8 = 18104000;
      F_WSPR = 18104600;
      break;
    case 15:
      F_FT8 = 21074000;
      F_FT4 = 21140000;
      F_JS8 = 21078000;
      F_WSPR = 21094600;
      break;
    case 10:
      F_FT8 = 28074000;
      F_FT4 = 28180000;
      F_JS8 = 28078000;
      F_WSPR = 28124600;
      break;
  }
}
//************************[ End of Frequency assign function ]*************************

//******************************[ Band  Assign Function ]******************************

void Band_assign() {
  digitalWrite(WSPR, LOW);
  digitalWrite(JS8, LOW);
  digitalWrite(FT4, LOW);
  digitalWrite(FT8, LOW);

  EEPROM.get(50, Band_slot);

  switch (Band_slot) {
    case 1:
      Band = Band1;
      blinkLED(WSPR, Bdly, 3);
      break;
    case 2:
      Band = Band2;
      blinkLED(JS8, Bdly, 3);
      break;
    case 3:
      Band = Band3;
      blinkLED(FT4, Bdly, 3);
      break;
    case 4:
      Band = Band4;
      blinkLED(FT8, Bdly, 3);
      break;
  }

  delay(1000);
  Freq_assign();
  Mode_assign();
}
//***************************[ End of Band assign function ]***************************

//*******************************[ Manual TX FUNCTION ]********************************
void ManualTX() {

  digitalWrite(RX,LOW);
  si5351.output_enable(SI5351_CLK1, 0);   // RX off
  digitalWrite(TX,HIGH);
  si5351.set_freq((freq*100ULL), SI5351_CLK0);
  si5351.output_enable(SI5351_CLK0, 1);   // TX on
  TX_State = 1;
  TXSW_State = digitalRead(TXSW);

  while (TXSW_State == LOW) {  // As long as TX is pressed
    TXSW_State = digitalRead(TXSW);
    if (cat_stat == 1) CAT_control();
    delay(50);
  }

  digitalWrite(TX,LOW);
  si5351.output_enable(SI5351_CLK0, 0);   // TX off
  TX_State = 0;
}

//********************************[ END OF Manual TX ]*********************************

//******************************[ BAND SELECT Function]********************************
void Band_Select() {

  digitalWrite(TX,HIGH);
  EEPROM.get(50, Band_slot);

  digitalWrite(WSPR,LOW);
  digitalWrite(JS8, LOW);
  digitalWrite(FT4, LOW);
  digitalWrite(FT8, LOW);

  switch (Band_slot) {
    case 1:
      blinkLED(WSPR, Bdly, 3);
      break;
    case 2:
      blinkLED(JS8, Bdly, 3);
      break;
    case 3:
      blinkLED(FT4, Bdly, 3);
      break;
    case 4:
      blinkLED(FT8, Bdly, 3);
      break;
  }

  while (TXSW_State == HIGH) {  // Use TX switch to end Band select

    switch (Band_slot) {
      case 1:
        digitalWrite(WSPR, HIGH);
        digitalWrite(JS8, LOW);
        digitalWrite(FT4, LOW);
        digitalWrite(FT8, LOW);
        break;
      case 2:
        digitalWrite(JS8, HIGH);
        digitalWrite(WSPR, LOW);
        digitalWrite(FT4, LOW);
        digitalWrite(FT8, LOW);
        break;
      case 3:
        digitalWrite(FT4, HIGH);
        digitalWrite(WSPR, LOW);
        digitalWrite(JS8, LOW);
        digitalWrite(FT8, LOW);
        break;
      case 4:
        digitalWrite(JS8, LOW);
        digitalWrite(WSPR, LOW);
        digitalWrite(FT4, LOW);
        digitalWrite(FT8, HIGH);
        break;
    }

    UP_State = digitalRead(UP);
    DOWN_State = digitalRead(DOWN);
    TXSW_State = digitalRead(TXSW);
    
    if ((UP_State == LOW) && (DOWN_State == HIGH)) {
      delay(100);
      UP_State = digitalRead(UP);
      if ((UP_State == LOW) && (DOWN_State == HIGH)) {
        Band_slot = Band_slot - 1;
        if (Band_slot < 1) {
          Band_slot = 4;
        }
      }
    }

    if ((UP_State == HIGH) && (DOWN_State == LOW)) {
      delay(100);
      DOWN_State = digitalRead(DOWN);
      if ((UP_State == HIGH) && (DOWN_State == LOW)) {
        Band_slot = Band_slot + 1;
        if (Band_slot > 4) {
          Band_slot = 1;
        }
      }
    }
  }
  
  digitalWrite(TX,0);
  EEPROM.put(50, Band_slot);

  Band_assign();
}

//*********************************[ END OF BAND SELECT ]*****************************


//************************** [SI5351 VFO Calibration Function] ************************

void Calibration(){

  digitalWrite(FT8, LOW);
  digitalWrite(FT4, LOW);
  digitalWrite(JS8, LOW);
  digitalWrite(WSPR, LOW);

  for (int i = 0; i < 3; i++) {
    digitalWrite(WSPR, HIGH);
    digitalWrite(FT8, HIGH);
    delay(Bdly);
    digitalWrite(WSPR, LOW);
    digitalWrite(FT8, LOW);
    delay(Bdly);
  }
  
  digitalWrite(WSPR, HIGH);
  digitalWrite(FT8, HIGH);

  EEPROM.get(10, cal_factor);

  // Set CLK2 output
  si5351.set_correction(cal_factor, SI5351_PLL_INPUT_XO);
  si5351.set_freq(Cal_freq * 100ULL, SI5351_CLK2);
  si5351.drive_strength(SI5351_CLK2, SI5351_DRIVE_2MA); // Set for lower power for calibration
  si5351.set_clock_pwr(SI5351_CLK2, 1); // Enable the clock for calibration

  TXSW_State = digitalRead(TXSW);

  while (TXSW_State == HIGH) {  // Use TX switch to end calibration

    UP_State = digitalRead(UP);

    if (UP_State == LOW) {
      delay(100);

      UP_State = digitalRead(UP);
      if (UP_State == LOW) {
        cal_factor = cal_factor - 100;
        si5351.set_correction(cal_factor, SI5351_PLL_INPUT_XO);
        TXSW_State = digitalRead(TXSW);
        continue;
      }
    }

    DOWN_State = digitalRead(DOWN);

    if (DOWN_State == LOW) {
      delay(100);
      DOWN_State = digitalRead(DOWN);
      if (DOWN_State == LOW) {
        cal_factor = cal_factor + 100;
        si5351.set_correction(cal_factor, SI5351_PLL_INPUT_XO);
        TXSW_State = digitalRead(TXSW);
        continue;
      }
    }
    delay(100);
    TXSW_State = digitalRead(TXSW);
  }

  EEPROM.put(10, cal_factor);           // Write cal_factor to EEProm
  si5351.set_clock_pwr(SI5351_CLK2, 0); // Disable the clock after calibration
  blinkLED(TX, Bdly, 3);
}

//****************************** [ End Of Calibration Function ]****************************************

//*********************************[ INITIALIZATION FUNCTION ]******************************************
void INIT() {

  EEPROM.get(30,temp);

  if (temp != 100) {
    // INIT EEPROM WITH DEFAULTS
    EEPROM.put(10, 100000); // cal_factor
    EEPROM.put(30, 100);    // EEPROM OK
    EEPROM.put(40, 4);      // Default Mode 1
    EEPROM.put(50, 1);      // Default Band 1
  }
  else {
    // READ EEPROM VALUES
    EEPROM.get(10, cal_factor);
    EEPROM.get(40, mode);
    EEPROM.get(50, Band_slot);
  }
}

//********************************[ END OF INITIALIZATION FUNCTION ]*************************************

//*********************************[ LED BLINK FUNCTION ]******************************************

void blinkLED(int ledPin, int blinkTime, int numBlinks) {
  pinMode(ledPin, OUTPUT);
  for (int i = 0; i < numBlinks; i++) {
    digitalWrite(ledPin, HIGH);
    delay(blinkTime);
    digitalWrite(ledPin, LOW);
    delay(blinkTime);
  }
}
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
